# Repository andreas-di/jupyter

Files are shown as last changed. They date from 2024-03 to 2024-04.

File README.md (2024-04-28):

# Frei stehender Bogen (aus 3D-gedruckten Klötzen)

Hier findet man Dateien, welche im Zuge einer Facharbeit zur mathematischen Kettenlinie entstanden sind.
In dieser wurde ein frei stehender Bogen aus 3D gedruckten Klötzen konstruiert.

<center>

</center>

<center>
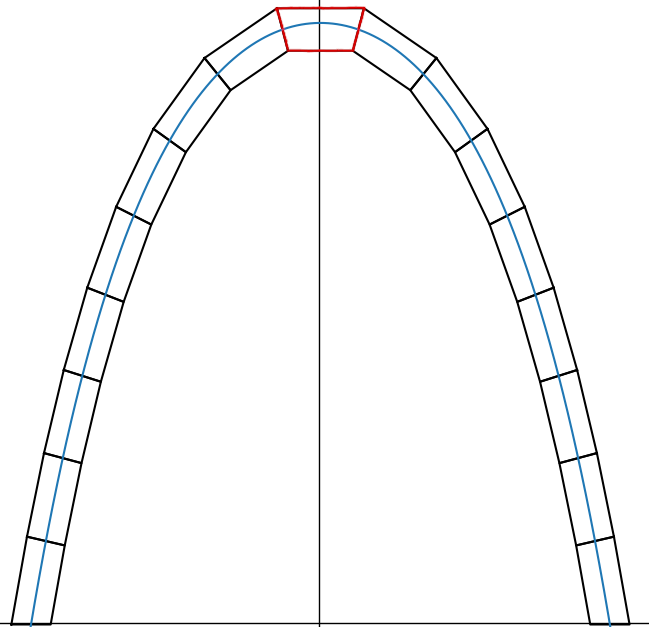
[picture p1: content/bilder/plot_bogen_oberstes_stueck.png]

</center>

Die ausführliche Facharbeit findet sich unter dem Namen Kettenlinie.pdf. Für klickbare Links bitte herunterladen und lokal öffnen.

Die Python Datei (Kettenlinie.py) erzeugt die für den Druck benötigten stl-Dateien (bei vorgegebenen Parametern) und simuliert die Klötze zweidimensional (siehe Abbildung).

Ein Jupyter-Notebook mit dem Python Code und weiterer Programm Dokumentation finden Sie [hier](https://andreas-di.github.io/jupyter/lab/index.html?path=Kettenlinie.ipynb).

Die stl-Dateien sind fertig druckbar, für einen Bogen der Länge 68cm, der Breite 30cm (am Boden). Insgesamt besteht die hier beschriebene Bogen aus 17 Klötzen, die jeweils ca. 4cm lang sind und einen Querschnitt von 2cmx2cm haben.

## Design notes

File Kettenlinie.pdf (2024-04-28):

## Die Kettenlinie Theoretische Eigenschaften und Anwendung beim Bau eines frei stehenden Bogens

Facharbeit von Andreas Diewald

### 8. M¨arz 2024

1

2

### Inhaltsverzeichnis

1 Einleitung | 3
2 Grundlagen: Herleitung der Bogenl¨ange | 5
3 Drehmatrix | 7
4 Grundlagen: Hyperbelfunktionen | 8
5 Grundlagen Kettenlinie | 12
6 Freistehender Bogen | 16

### 6.5.2 Zus¨atzliches L¨angenstuck | 29 ¨

7 Anwendung in der Architektur | 35
8 Fazit | 39
9 Literaturverzeichnis und Eigenst¨andigkeitserkl¨arung | 40

### 10 Anhang

### 10.1 Grundlagen: Matrix Vektor Rechnung | 10.1.1 Graphische Darstellung Vektoren | 10.1.2 Betrag eines Vektors | 10.1.3 Addition von Vektoren | 10.1.4 Matrix-Vektor-Multiplikation | 10.2 Numerische Werte |

3

### 1 Einleitung

Ein Jupyter-Notebook, mit dem Python-Code zu dieser Arbeit, finden Sie hier:

https://andreas-di.github.io/jupyter/lab/index.html?path=Kettenlinie.ipynb

Die vorliegende Facharbeit und weitere Dateien, wie zum Beispiel die fertig druckbaren stl-Dateien, finden Sie hier:

https://github.com/andreas-di/jupyter.

Diese Facharbeit besch¨aftigt sich mit der mathematischen Kettenlinie. Die Kettenlinie (auch Katenoide genannt) ist die mathematische Kurve, die eine Kette beschreibt, die an zwei Punkten aufgehangen ist und nach Einwirkung der Schwerkraft in der Ruhelage h¨angt.

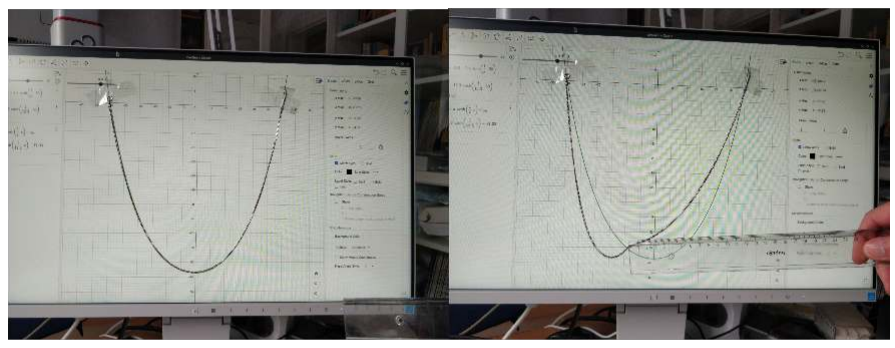
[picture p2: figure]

Abbildung 1: Eine Halskette ist mit Tesafilm am Bildschirm befestigt und man erkennt, dass ihre Form genau mit der mathematischen Katenoide ubereinstimmt. ¨

4

Ich werde auf die mathematische Beschreibung der Kettenlinie eingehen und diese anschließend an einem spezifischen Beispiel durch einen Bogen simulieren.
Dieser besteht aus einzelnen Kl¨otzen ohne statische Verbindung, welche zu einem Bogen zusammengesetzt sind. Dieses Modell illustriert besonders deutlich die zentrale Eigenschaft der Kettenlinie, wonach in keinem Punkt seitliche Schubkr¨afte wirken.
Abschließend werde ich auf die historische Bedeutung und Anwendung im Bereich der Architektur eingehen.

Erst einmal folgt jedoch eine knappe Schilderung der Geschichte der Kettenlinie.

Geschichte

Galilei (1564 bis 1642) besch¨aftigte sich erstmals mit der Kettenlinie. Er vermutete, dass die Kettenlinie, zwar nicht gleich, aber ¨ahnlich einer Parabel sei. Diese These widerlegte jedoch Joachim Jungius (1587 bis 1657) in seiner 1639 erschienenen ”

Geometria empyrica“.
Christian Huygens (1629 bis 1695) zeigt 1646 ebenfalls, dass es sich bei der Kettenlinie nicht um einem Parabel handeln k¨onne. Da Huygens jedoch nicht in der Lage war, die Kettenlinie mathematisch zu beschreiben, bat er Leibniz darum.
Die exakte Herleitung der Kettenlinie erfolgte dann erstmals 1690 durch Gottfried Wilhelm Leibniz. Da Leibniz sich bei seiner L¨osung unsicher war, rief er zum Wettbewerb auf, die Kettenlinie herzuleiten. Im Zuge dieses Wettbewerbs leiteten auch Huygens und Johann Bernoulli die mathematisch korrekte Beschreibung der Kettenlinie her.
Diese L¨osungen wurden schließlich im Juni 1691 ver¨offentlicht.

Die Darstellung der geschichtlichen Erarbeitung der Kettenlinie ist einer Ausarbeitung von [Hajiabadi] entnommen.

Gliederung der Facharbeit

Der theoretischen Erarbeitung der Kettenlinie in Kapitel 5 und dem Bau des Bogens (Ka-
pitel 6) sind die fur den Bau ben ¨ | ¨otigten Grundlagen vorangestellt (Kapitel 2 bis Kapitel
4).
Anschließend folgt die Herleitung der mathematischen Beschreibung der Kettenlinie in Kapitel 5 und die Dokumentation des Bogenbaus (Kapitel 6). Abschließend wird die historische Bedeutung der Kettenlinie in Kapitel 7 dargestellt.

5

### 2 Grundlagen: Herleitung der Bogenl¨ange

Die Bogenl¨ange ist die L¨ange, die man auf der Funktion zwischen zwei Punkten A und B
zurucklegt (siehe Abbildung 2). Legt man beispielsweise eine Schnur ¨ | uber den Funktions- ¨
graphen zwischen den beiden Punkten, ist die L¨ange der Schnur die Bogenl¨ange.

Abbildung 2: Bogenl¨ange L zwischen zwei Punkten

Um im Weiteren auf die L¨ange des freistehenden Bogens eingehen zu k¨onnen, ben¨otige ich
die allgemeine Formel fur die Bogenl ¨ | ¨ange zwischen zwei Punkten A und B.

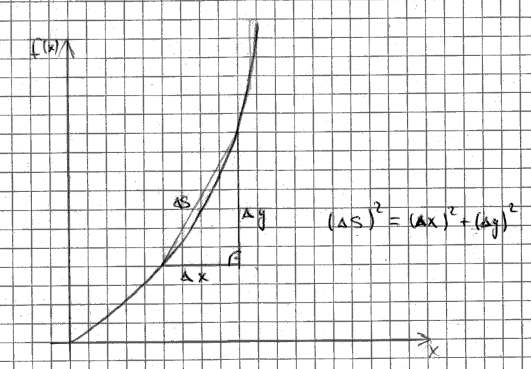
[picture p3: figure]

Abbildung 3: Ansatz Berechnung der Bogenl¨ange

6

Nach Abbildung 3 und dem Satz des Pythagoras gilt:

(∆s)

2 = (∆x)

2 + (∆y)

2
| : (∆x)

2
∆s
∆x

2
= 1 +
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
| · ∆x

(1)

Fur den Grenzfall ∆ ¨ | x → 0 gilt
∆y
∆x

2
= (f

′

(x))²
, also

ds =

q
1 + (f

′(x))²
- dx | (2)

Die Bogenl¨ange L ist die Summe aller L¨angenelemente ds auf der Strecke zwischen A und B.

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
1 + (f

′(x))²
dx | (3)
Die Formel fur die Bogenl ¨ | ¨ange findet man unter anderem in [Formelsammlung, S. 24].

7

### 3 Drehmatrix

Da in einem sp¨ateren Abschnitt in Kapitel 6.7 Punkte in einem Koordinatensystem gedreht und verschoben werden, ben¨otige ich noch Drematrizen. Daher werden diese zun¨achst noch behandelt.
Grundlagen im Bereich der Vektor-Matrix-Rechnung befinden sich im Anhang.

Der Vektor ⃗v soll gedreht um den Winkel α den Vektor ⃗v′ ergeben (siehe Abbildung 4).

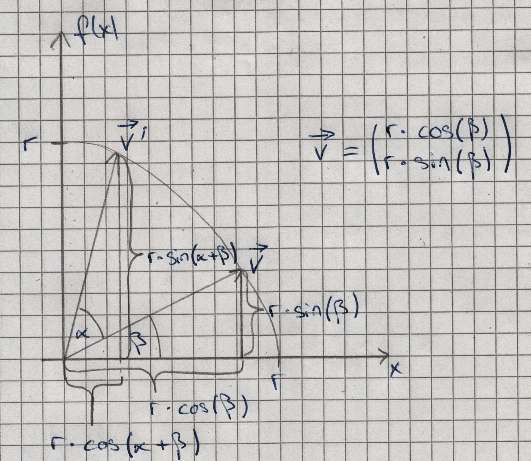
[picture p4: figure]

Abbildung 4: Der Vektor ⃗v wird mit der Drehmatrix gedreht. Der gedrehte Vektor ist hier bezeichnet mit ⃗v′

⃗v′ =

r · cos(α + β)
r · sin(α + β)
(4)
Mit den Additionstheoremen [Formelsammlung, S.14], [Muller-Fonfara, S. 318] f ¨ | ur die ¨
trigonometrischen Funktionen
sin(a + b) = sin(a) · cos(b) + cos(a) · sin(b) | (5)
cos(a + b) = cos(a) · cos(b) − sin(a) · sin(b)

ergibt sich aus Gleichung (4):

⃗v′

(5)
=
r · cos(α) · cos(β) − sin(α) · sin(β) r · sin(α) · cos(β) + cos(α) · sin(β)

| (6)

Dies kann man als Matrix-Vektor-Multiplikation (siehe Anhang Gleichung (34)) schreiben:

8

⃗v′ =

cos(α) − sin(α)
sin(α) cos(α)
·
r · cos(β)
r · sin(β)

Wobei
r · cos(β)
r · sin(β)
= ⃗v ist. Also gilt:

⃗v′ = D · ⃗v

Mit D als Drehmatrix:

D =

cos(α) − sin(α)
sin(α) cos(α)
(7)
Diese Formel fur die Drehmatrix findet man in [Fischer, S. 203] oder auch [Athen/Bru ¨ | hn,
S. 208].

### 4 Grundlagen: Hyperbelfunktionen

Da die Kettenlinie durch eine cosh-Funktion beschrieben wird, ben¨otige ich im Folgenden noch einige Grundlagen dazu. Daher werden dieses hier behandelt.

### 4.1 Cosinus hyperbolicus

Die Funktion cosh ist definiert als:

cosh(x) := e

x + e

−x
2
[Formelsammlung, S.25] | (8)

Graphische Veranschaulichung:

Abbildung 5: cosh als die ”

H¨alfte “der Summe von e

x und e

−x

9

f(x) = e

x

g(x) = e

−x

h(x) = f(x) + (g(x))
2

=

e

x + e

−x
2
= cosh(x)

Die cosh Funktion ist also die ”

H¨alfte “der Summe von e

x und e

−x

### 4.2 Sinus hyperbolicus

Die Funktion sinh ist definiert als: sinh(x) := e

x − e

−x
2
[Formelsammlung, S.25] | (9)

Graphische Veranschaulichung:

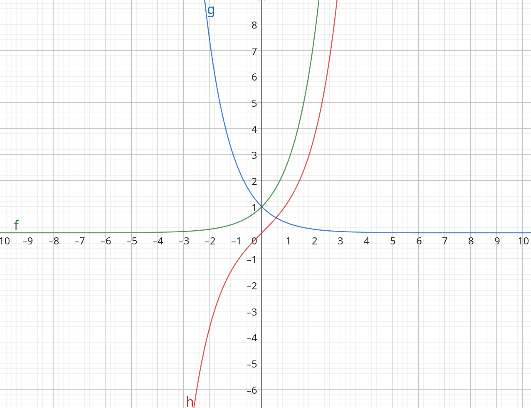
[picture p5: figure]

Abbildung 6: sinh als die ”

H¨alfte “der Subtraktion von e

x und e

−x

f(x) = e

x

g(x) = e

−x

h(x) = f(x) − (g(x))
2

=

e

x − e

−x
2
= sinh(x)

Die sinh Funktion ist also die ”

H¨alfte “der Differenz von e

x und e

−x

10

### 4.3 Ableitungen

Beim sp¨ateren Bau des freistehenden Bogen, werden die Ableitungen der cosh und sinh Funktion ben¨otigt. Daher werden diese auch noch hergeleitet.

### 4.3.1 Cosinus hyperbolicus

Mit der Kettenregel erh¨alt man:

cosh′

(x) =
e

x + e

−x
2

′

=

(e

x
)

′ + (e

−x
)

′
2

=

e

x + e

−x
- (−1)
2

=

e

x − e

−x
2

Da e

x−e⁻x
2 = sinh(x) ist, gilt:
cosh′
(x) = sinh(x) | (10)

### 4.3.2 Sinus hyperbolicus

Mit der Kettenregel eribt sich:

sinh′

(x) =
e

x − e

−x
2

′

=

(e

x
)

′ − (e

−x
)

′
2

=

e

x − e

−x
- (−1)
2

=

e

x + e

−x
2

Da e

x+e⁻x
2 = cosh(x) ist, gilt:
sinh′
(x) = cosh(x) | (11)

11

### 4.4 Zusammenh¨ange zwischen cosh und sinh

Behauptung:

cosh²

(x) − sinh²
(x) = 1 | [Formelsammlung, S.25] | (12)

Beweis:

cosh²

(x) − sinh²
(x) =
e

x + e

−x
2

2
−

| e x − e −x
| 2

2

=

e

2x + 2 · (e
x
- e

−x
) + e

−2x
4

−

e

2x − 2 · (e
x
- e

−x
) + e

−2x
4

Da (e

x
- e

−x
) = 1 ist:

=

e

2x + 2 + e

−2x
4

−

e

2x − 2 + e

−2x
4

=

e

2x + 2 + e

−2x − e

2x + 2 − e

−2x
4
=

2 + 2
4
= 1 | q.e.d

12

### 5 Grundlagen Kettenlinie

Die Kettenlinie beschreibt die Linie, in der eine Kette, aufgehangen in zwei Punkten, in der Ruhelage h¨angt (siehe Abbildung 1 aus der Einleitung).

Eine h¨angende Kette hat die Eigenschaft, dass in jedem Punkt der Kette nur tangentiale Kr¨afte wirken. Die seitliche Schubkr¨afte stehen im Gleichgewicht.
Im folgenden Unterkapitel 5.1 wird hergeleitet, dass sich eine Kettenlinie durch die Funktion
f(x) = a cosh
1
a

x

+ y0

darstellen l¨asst.

### 5.1 Herleitung Kettenlinie

Die Herleitung folgt der Darstellung von [Stifel]. Außerdem ist die Herleitung bei [Lern-Helfer]
zu finden. Einer ausfuhrlichere Ausarbeitung ist auch in [Gl ¨ | uck, S. 2] dargestellt. ¨

Betrachtet wird hier eine Kette, welche an zwei Punkten aufgehangen ist und in der Ruhelage h¨angt.
In Abbildungen 7 wird die Kettenlinie durch einzelne Massepunkte, die miteinander in Verbindung stehen, veranschaulicht. Die Kettenlinie wird hier ”

vergr¨oßert“dargestellt, indem nur einzelne Massepunkte eingezeichnet sind.

Abbildung 7: Kettenlinie simuliert durch einzelne Massepunkte

13

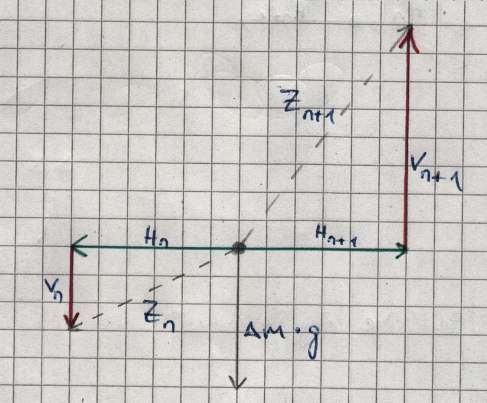
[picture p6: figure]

Abbildung 8: Einzelner Massepunkt auf der Kettenlinie

Betrachtet man einen einzelnen Massepunkt, wirken auf diesen die Kr¨afte Z, sowie die Gewichtskraft m · g.
Die Z Kr¨afte lassen sich jeweils in vertikale Kraftkomponenten V und horizontale Kraftkomponenten H unterteilen (siehe Abbildung 8).
Daher gilt bei einer Kette im Gleichgewicht:
Hn | = Hn+1 = konstant = H | (13)
Vn+1 | = Vn + ∆m · g | (14)

Gleichung (13) bedeutet, dass keine resultierenden seitlichen Schubkr¨afte wirken. Denn
wenn welche wirken wurden, w ¨ | urde sich die Form der Kette solange nach diesen ¨ | ¨andern,
bis keine mehr wirken wurden. ¨
Nur wenn Gleichung (13) gilt, h¨angt die Kette in Ruhelage.
Fur die Steigung der linken Seite des betrachteten Massepunkts gi ¨ | lt:
∆yn
∆xn

=

Vn
Hn

(15)

Und auf rechter Seite:
∆yn+1

∆xn+1

=

Vn+1

Hn+1

(16)

Da in der Ruhelage die vertikale Kraftkomponente nach unten aus der Gewichtskraft und der Teilkraft der entlang der Kette wirkenden Zugkraft entsteht (siehe Formel (14)) kann man Gleichung (16), auch schreiben als:

∆yn+1

∆xn+1

=

Vn + ∆m · g
H

=

Vn
H

+

∆m · g
H
(15)
=

∆yn
∆xn

+

∆m · g
H

14

Also ist die Steigung auf der rechten Seite gleich der Summe aus der Steigung auf der linken Seite und ∆m·g
H

∆yn+1

∆xn+1

−

∆yn
∆xn

:= ∆
∆y
∆x

Also ist die Steigung an einem beliebigen Punkt:

∆

∆y
∆x
=

∆m · g
H

(17)

Allgemein gilt:
∆m = ρ · ∆s | (18)
Wobei ρ die Masse pro L¨ange ist. Nach Einsetzten in Gleichung (17):

∆

∆y
∆x
(18)
=

ρ · ∆s · g
H

Durch Einsetzten von ∆s =

p
1 + (f

′(x))² · ∆x (siehe Grundlagen: Formel (3)), erh¨alt man:

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
ρ · g
H
- ∆x | : ∆x

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
ρ · g
H

(19)

y ist Funktion von x:

∆y
∆x

=

∆y(x)
∆x

−−→
lim ∆x→0

dy(x)
dx = y

′
(x)

Also:

∆

∆y
∆x

∆x

−−→
lim ∆x→0

∆y

′
∆x

−−→
lim ∆x→0

y

′′(x)

Also wird aus (19) die Differentialgleichung:

y

′′(x) = p
1 + (y

′(x))² ·

ρ · g
H

(20)

Ansatz zum L¨osen der Differenzialgleichung:

y(x) = a · cosh
1
a

x

+ y0 | (21)

Einsetzten von Ansatz (21) in die Differenzialgleichung (20):

a · cosh
1
a

x

− y0

′′ (21)
=

s
1 + a · cosh
1
a

x

− y0

′2
·

ρ · g
H

15

Nach Ableiten der Funktion (siehte Formel (10) und Formel (11)):

sinh
1
a

x

′
=

s
1 + sinh²
1
a

x

·

ρ · g
H

1
a
- cosh
1
a

x

=

s
1 + sinh²
1
a

x

·

ρ · g
H

Durch Beziehung cosh² − sinh² = 1 (siehe Grundlagen Hyperbelfunktionen, Gleichung (12) und Wurzel ziehen:

1
a
- cosh
1
a

x

= cosh
1
a

x

·

ρ · g
H

Wenn 1
a =

ρ·g
H wird die Differentialgleichung also erfullt durch: ¨

y(x) = a · cosh
1
a

x

+ y0

Im Folgenden werde ich die Bezeichung f(x) fur ¨ y(x) benutzen.

f(x) = a · cosh
1
a

x

+ y0 | (22)

16

### 6 Freistehender Bogen

H¨angt man an eine h¨angende Kette eine bestimmte Masse, bildet sich so die Kette so aus, dass keine seitlichen Schubkr¨afte wirken. Dreht man dieses Modell um, erh¨alt man den optimalen Bogen, um eine solche Masse zu tragen. Das liegt daran, dass genau wie bei der Kette in keinem Punkt seitliche Schubkr¨afte wirken. Diese Eigenschaft, erm¨oglichte das verwenden von H¨angemodellen in der Architektur (siehe Kapitel 7).

Dies gilt auch dann, wenn keine Masse auf dem Bogen lasten soll. Dann ist der optimale stabile Bogen die umgedrehte Kettenlinie.

Um zu veranschaulichen, dass bei einem solchen Bogen keine seitlichen Schubkr¨afte wirken, baue ich im Folgenden einen Bogen aus einzelnen Kl¨otzen, die nicht statisch miteinander
verbunden sind (siehe Abbildung 9). Wurden seitliche Schubkr ¨ | ¨afte wirken, wurden sich ¨
die Kl¨otze zur Seite weg schieben und der Bogen wurde zusammenbrechen. ¨

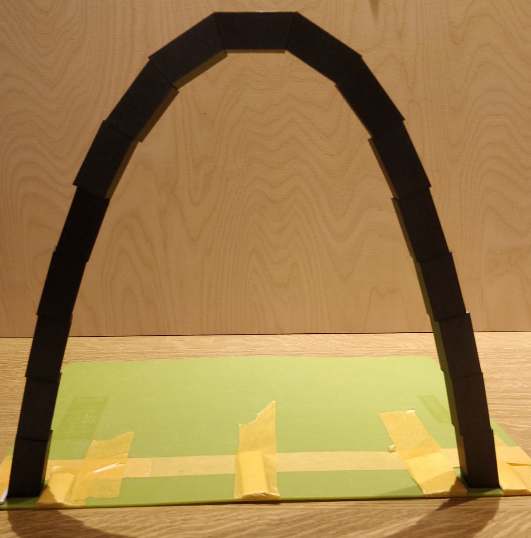
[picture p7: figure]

Abbildung 9: Freistehender Bogen aus einzelnen 3D-gedruckten Kl¨otzen. Die Kl¨otze stehen lose aufeinander und sind nicht miteinander verbunden.

17

Der Bogen wird auf dem Boden von zwei festgeklebten Erh¨ohungen festgehalten (siehe Abbildung 9). Das ist n¨otig, da an diesen stellen die Kraft von den oberen Kl¨otzen nicht komplett abgefangen wird (siehe Abbildung 10).

Abbildung 10: Die tangentiale Kraftkomponente F⃗B,t der vom Boden aufgebracht Kraft F⃗B ist kleiner als die tangentiale F⃗K1,u
. Daher ist die resutierende Kraft zur Seite gerichtet.

Da auf dem Bogen keine Masse lasten soll, wird dieser durch eine Kettenlinie beschrieben. Vor dem Bau des Bogens wird die L¨ange L und Breite B am Boden des Bogens festgelegt (siehe Abbildung 11).

18

Abbildung 11: L ist die Bogenl¨ange

Auch die Breite b und H¨ohe h der Kl¨otze (siehe Abbildung 12) werden festgelegt.

Abbildung 12: b ist die Breite des Klotzes, h seine H¨ohe

Hier wurden die Werte gew¨ahlt als:

L = 136LE
B = 60LE
b = 4LE
h = 4LE

19

Die bogenbeschreibende Funktionsgleichung soll so gew¨ahlt werden, dass der Teil unterhalb der x-Achse den Bogen beschreibt, (siehe Abbildung 13).
Daher gilt, dass die Nullstelle der Funktion x0 =

B
2 = 30LE und die Bogenl¨ange zwischen den Nullstellen −x0 und x0 gleich L ist.

Abbildung 13: Bogenbeschreibende Kettenlinie

Ich habe mich dafur entschieden, den Bogen aus 17 Kl ¨ | ¨otzen zu bauen.
Durch die ungerade Anzahl, ist der Bogen stabiler, da der obere Klotz waagerecht liegt (siehe Abbildung 14).

Abbildung 14: Oberster Klotz liegt waagerecht

### 6.1 Bogenl¨ange Kettenlinie

Um die Maße der einzelnen Kl¨otze bestimmen zu k¨onnen, muss im ersten Schritt die Funktionsgleichung der Kettenlinie bestimmt werden, die den Bogen simuliert.

20

Die bogenbeschreibende Funktion ist so ins Koordinatensystem gelegt, dass sie Achsensymmetrie aufweist und der Teil unterhalb der x-Achse den Bogen beschreibt (siehe Abbildung 15).

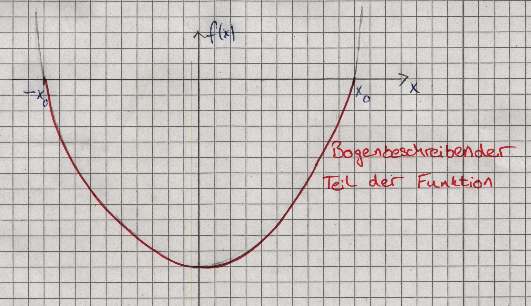
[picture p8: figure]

Abbildung 15: Teil der Kettenlinie, der den Bogen simuliert

Um den Faktor a der Kettenlinie f(x) = a · cosh

1
a

x

− y0 zu bestimmen, wird zuerst die
Gleichung fur die Bogenl ¨ | ¨ange L unterhalb der x-Achse aufgestellt.

Aus Abbildung 15 folgt, dass die Bogenl¨ange zwischen den beiden Nullstellen −x0 und
x0 gleich der L¨ange L des Bogens sein muss. Mit Formel (3) fur die allgemeine Bogenl ¨ | ¨ange
gilt:

L =

Z x0

−x0

q
1 + (f

′(x))²
dx

Da die Kettenlinie durch eine cosh Funktion beschrieben wird ( f(x) = a · cosh

1
a

x

siehe
Formel (22)), und diese abgeleitet f

′

(x) = sinh

1
a

x

ergibt (siehe Formel (10)), wird aus dieser Gleichung:

L

(10)
=

Z x0

−x0

s
1 + sinh²
1
a

x

dx | (23)

Durch die Beziehung cosh²

(x) − sinh²
(x) = 1 (siehe Grundlagen Gleichung (12)), kann man Gleichung(23) auch schreiben als:

L

(12)
=

Z x0

−x0

s
cosh²
1
a

x

dx

=

Z x0

−x0

cosh
1
a

x

dx

(11)
=

a · sinh
1
a

x

x0

−x0
= a · sinh
1
a

x0

−

a · sinh
−

1
a

x0

| (24)

21

Da die sinh Funktion punktsymmetrisch ist, gilt a ·sinh
−

1
a

x0

= −

a · sinh

1
a

x0

. Und
da (−1) · (−1) = +1 ist, kann man Gleichung (24) auch schreiben als:

L = 2a · sinh
1
a

x0

(25)

Alle Werte bis auf a sind konstant. ( x0 = 30LE und L = 136LE )
Mit Hilfe dieser Gleichung wird im nachfolgenden Kapitel der Fakor a der Funktion bestimmt.

### 6.2 Bestimmung Faktor a

Zur Beschreibung einer konkreten Kettenlinie muss der Faktors a der Funktionsgleichung (Gleichung (22)) fur die Kettenlinie bestimmt werden. ¨
L = 136LE = konstant
x0 = 30LE = konstant

L

| (25) = | 2a · sinh
| | 1 a x0

| − 2a · sinh
1
a

x0

0 | = | L − 2a · sinh
1
a

x0

(26)

Betrachtet man nun g(a) := L − 2a · sinh

1
a

x0

als Funktion von a, sind die Nullstellen dieser Funktion gesucht.
Der Wert a wird, mit einem Python-Programm (siehe Anhang) mittels Intervallhalbierung, numerisch bestimmt, da es nicht m¨oglich ist, Gleichung (26) algebraisch nach a umzustellen.

Mit den von mir verwendeten Parametern (L = 136LE, x0 = 30LE) ergibt sich mit Hilfe des Python-Programmes die Nullstelle:

| | a ≈ 12, 54

Der Wert a ist auf zwei Nachkommastellen gerundet. (Genauere Angaben befinden sich im Anhang.)

Damit sind nun alle Konstanten in der Kettenlinie (22) bestimmt. Der Faktor y0 wurde ermittelt, indem die Funktion der Kettenlinie an der Nullstelle x0 gleich Null gesetzt wurde. Dieser Ausdruck wurde nach y0 umgestellt (y0 = −a · cosh

1
a

x0

). Da a und x0 bekannt
sind, kann y0 bestimmt werden.
| | y0 ≈ −69.15

Auch dieser Wert wurde mittels des Pythonprogramms bestimmt und ist auf zwei Nachkommastellen gerundet.

22

### 6.3 Bestimmung x Wert bei gegebener Bogenl¨ange auf der Funktion

Hier wird die Kettenlinie erstmalig in gleich lange Stucke unterteilt. Dieses St ¨ | ucke werden ¨
sp¨ater durch Kl¨otze simuliert.
Die gesamte Bogenl¨ange wird durch Formel (23): L =

R x0

−x0

q
1 + sinh²

1
a

x

| dx bestimmt.

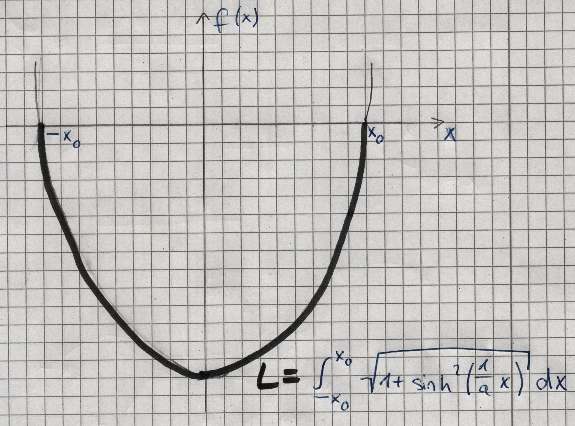
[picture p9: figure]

Abbildung 16: Bogenl¨ange zwischen den Nullstellen

Also wird die Bogenl¨ange von 0 bis zu einer Stelle x durch das Integral von 0 bis x bestimmt.

Abbildung 17: Bogenl¨ange zwischen der Stelle 0 und x

23

l

!=

Z x

0

q
1 + (f

′(x))²
dx =

Z x

0

s
1 + sinh²
1
a

x

dx

Mit der Beziehung cosh² − sinh² = 1 (siehe Formel (12)):

l

(12)
=

Z x

0

cosh
1
a

x

dx (11)
=

a · sinh
1
a

x

x

0
| = | a · sinh
| | 1 a x

− a · sinh
1
a
- 0

a · sinh
1
a
- 0

= 0
(27)
| (27)
| = | a · sinh
| | 1 a x
| : a
l a | = | sinh
| | 1 a x
| arcsinh(·)

arcsinh
l
a
| = | 1 a
- x | | · a
x | = | a · arcsinh
l
a
(28)

Mit dieser Formel l¨asst sich ein x-Wert x in Abh¨angigkeit von eine Bogenl¨ange l bestimmen. Also ist x eine Funktion von l, x = x(l) = a · arcsinh

l
a
Die Konstante a ist hier a ≈ 12, 5 (wie in Kapitel 6.2 bestimmt).

Die Bogenl¨ange L der Funktion wird in gleichlange Teile unterteilt (siehe Abbildung 18), wobei jeder dieser Teile durch einen Klotz des Bogens simuliert werden soll.

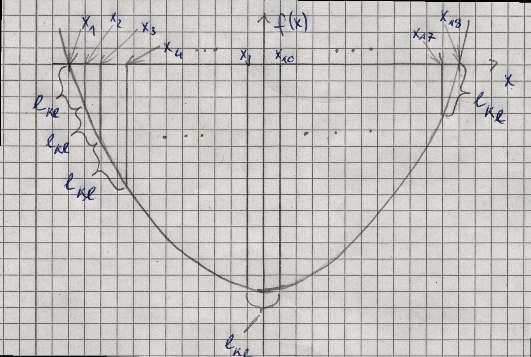
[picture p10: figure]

Abbildung 18: Bogenl¨ange unterteilt in Teill¨ange lKl

24

Die durch einen Klotz beschriebene Bogenl¨ange lKl, ist also die gesamte L¨ange L des Bogens geteilt durch die Anzahl der Kl¨otze.
Fur die Anzahl der Kl ¨ | ¨otze habe ich eine ungerade Anzahl anzahlk = 17 gew¨ahlt, sodass
der oberste Klotz des Bogens waagerecht liegt (siehe Abbildung 14).
Da ich L = 136LE gew¨ahlt habe, ist die durch einen Klotz beschriebene Bogenl¨ange hier

lKl =

136LE
17 = 8LE.
Um die Liste der x-Werten zu erhalten muss l1 nun bei −

L
2

starten und in jedem Schritt um lKl erh¨oht werden, bis l18 =

L
2

(siehe Abbildung 19).
Diese Werte fur ¨ ln werden in die Formel (28) fur einen x-Wert in Ah ¨ | ¨angigkeit der Bo-

Abbildung 19: Bogenl¨ange ln fur ¨ n = 1 und n = 2

genl¨ange l eingesetzt.
Also gilt fur den ¨ n-ten x-Wert

xn = a · arcsinh
ln
a

mit a ≈ 12, 5 und

ln = −

L
2
+ (n − 1) · lk | (29)

wobei
n = 1, 2, 3..., 18

Also ist fur ¨ n = 1 die zugeh¨orige Bogenl¨ange l1 = −

L
2

und x1 = −x0. Das gleiche gilt fur ¨ n = 18 auf positiver Seite. Also l18 =

L
2

und somit x18 = x0.

i | 1 | 2 | 3 | 4 | 5 | 6 | 7 | 8 | 9 | 10 | 11 | 12 | 13 | 14 | 15 | 16 | 17 | 18
ln | -68.0 | -60.0 | -52.0 | -44.0 | -36.0 | -28.0 | -20.0 | -12.0 | -4.0 | 4.0 | 12.0 | 20.0 | 28.0 | 36.0 | 44.0 | 52.0 | 60.0 | 68.0
xi | -30.0 | -28.5 | -26.7 | -24.7 | -22.3 | -19.4 | -15.6 | -10.7 | -3.9 | 3.9 | 10.7 | 15.6 | 19.4 | 22.3 | 24.7 | 26.7 | 28.5 | 30.0
f(xi) | 0.0 | -7.9 | -15.7 | -23.4 | -31.0 | -38.5 | -45.5 | -51.8 | -56.0 | -56.0 | -51.8 | -45.5 | -38.5 | -31.0 | -23.4 | -15.7 | -7.9 | 0.0
Die Werte in der Tabelle habe ich mittels einer for-Schleife in einem Pythonprogramm ermittelt (siehe Anhang).
Die x- und f(x)−Werte werden ben¨otigt, um die L¨angen der Kl¨otze und die Schneidewinkel an den Seiten der Kl¨otze zu bestimmen.

25

### 6.4 Bestimmung der Schneidewinkel

Um die Kl¨otze zu bauen werden die Schneidewinkel ben¨otigt, unter denen sich die Kl¨otze beruhren. Dieses werden in diesem Kapitel berechnet. ¨
Die Kl¨otze liegen so auf der Funktion, dass der Funktionsgraph genau durch die Mitte der R¨ander des Klotzes geht (siehe Abbildung 20). An diesen Stellen befinden sich die Punkte der x-Werte (siehe Abbildung 20).

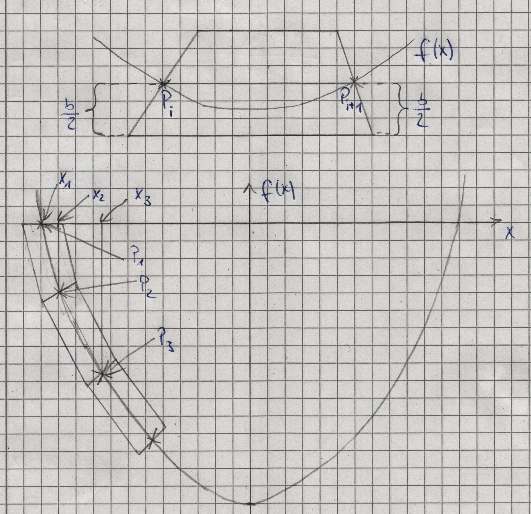
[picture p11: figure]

Abbildung 20: Lage des Funktionsgraphen in einem Klotz

Um den optimalen Bogen zu erhalten, mussten die Schneidewinkel in einem 90 ¨

◦
-Winkel
auf den wirkenden Kr¨aften stehen. Da hier die Kr¨afte tangential wirken (siehe Grundlagen Kettenlinie), w¨aren die korrekten Schneidewinkel die Normalen-Steigungswinkel.

H¨atten die Kl¨otze keine Breite, w¨are es m¨oglich diese als Schneidewinkel zu verwenden.
Doch da die Kl¨otze eine Breite haben, wurden die Kl ¨ | ¨otze nicht genau aufeinander auflie-
gen, wurde man die Normalen-Steigungswinkel verwenden, (siehe Abbildun ¨ | g 21).

26

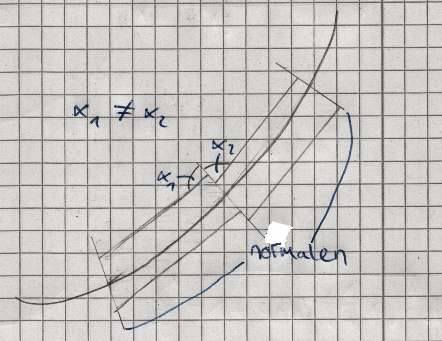
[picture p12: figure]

Abbildung 21: Lage der Kl¨otze mit Normalen als Schnitte. Die Kl¨otze wurden nicht genau ¨ aufeinander aufliegen.

Da die Außenseiten der Kl¨otze parallel zu der Sekanten durch die beiden x-Werte sind (siehe Abbildung 20), liegen die Kl¨otze genau aufeinander auf, wenn der Winkel zwischen diesen gleich dem zwischen den jeweiligen Sekanten ist.

Der Schneidewinkel λ ist dementsprechend die H¨alfte des Winkels γ zwischen den jeweiligen Sekanten, (siehe Abbildung 22).

Abbildung 22: Winkel λ =

180◦−α2+α1
2

zwischen den Kl¨otzen (siehe Formel (30))

Also gilt fur den Schneidewinkel ¨ | λ zwischen zwei Kl¨otzen:
| λ = 180◦ − α2 + α1
| 2

(30)

27

Wobei α1 und α2 die Sekanten-Steigungswinkel der jeweiligen Sekanten aus Abbildung 22 sind.

Besonderheit bei dem ersten und letzten Klotz

Da die Schneidewinkel λ jeweils von zwei Sekantensteigungen α abh¨angig sind, wurde man ¨
fur den ersten und letzten Klotz keinen Schneidewinkel an der x- ¨ | Achse erhalten, da dort
ein weiterer Sekanten-Steigungswinkel fehlt.
Da mein Python-Programm aus den Sekantensteigungswinkeln automatisch die Schneidewinkel und daraus die Klotzmaße ermittelt, w¨are es umst¨andlich, in jedem Schritt den ersten und letzten Klotz gesondert zu behandeln.
Um dies zu umgehen, habe ich den ersten und letzten Klotz an der x-Achse gespiegelt (siehe Abbildung 23) und die Sekantensteigungswinkel, die sich fur diese gespiegelten Se- ¨ kanten ergeben an die erste und letzte Stelle der Liste gestellt. Fur den ersten und letzten ¨ Schneidewinkel λ1 und λ18 gilt also λ1 = α1 und λ18 = α17 (siehe Abbildung 23)

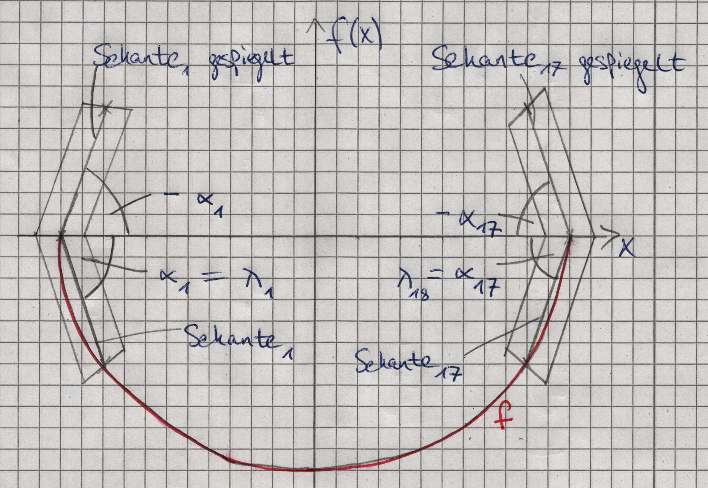
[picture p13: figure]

Abbildung 23: Erster und letzter Klotz an der x-Achse gespiegelt

Mit diesem Trick, k¨onnen alle anderen Funktionen meines Python-Programmes wie ge-
wohnt uber die als Parameter ben ¨ | ¨otigten Listen iterieren, ohne Ausnahmen beim ersten
und letzten Klotz machen zu mussen. Andernfalls m ¨ | usste in der Liste der Schneidewinkel ¨
an ersten und letzter Stelle der jeweilige Sekanten-Steigungswinkel angegeben werden.

28

Numerische Ergebnisse

In der nachfolgenden Tabelle sind die verwendeten Schneidewinkel λ dargestellt. Die Werte in der Tabelle wurden genau wie die x-Werte mit dem Pythonprogramm berechnet (siehe Anhang).

i | 1 | 2 | 3 | 4 | 5 | 6 | 7 | 8 | 9 | 10 | 11 | 12 | 13 | 14 | 15 | 16 | 17 | 18
λ | 78.9 | 89.23 | 88.98 | 88.61 | 87.98 | 86.86 | 84.66 | 80.19 | 74.04 | 74.04 | 80.19 | 84.66 | 86.86 | 87.98 | 88.61 | 88.98 | 89.23 | 78.9

### 6.5 Bestimmung der Klotz-Ausmaße

Zum Drucken der Kl¨otze werden die genauen Abmaße der Kl¨otze ben¨otigt. Diese werden in diesem Unterkapitel berechnet.

### 6.5.1 L¨ange der Sekante

Die Sekante, die den Klotz darstellt, verl¨auft an dessen Seiten genau durch die Mitten (siehe Abbildung 20). Also genau durch die Punkte, die den Klotz in seiner Lage festlegen. Jede Sekante ist, wie der zugeh¨orige Klotz von zwei Punkten und somit den zwei x-Werten abh¨angig (siehe Abbildung 24). Der Index der Sekanten gibt an, durch welche Punkte diese verl¨auft (beispielsweise verl¨auft die Sekante s1,2 durch den Punkt mit dem zugeh¨origen x-Wert x1 und den Punkt mit x-Wert x2):

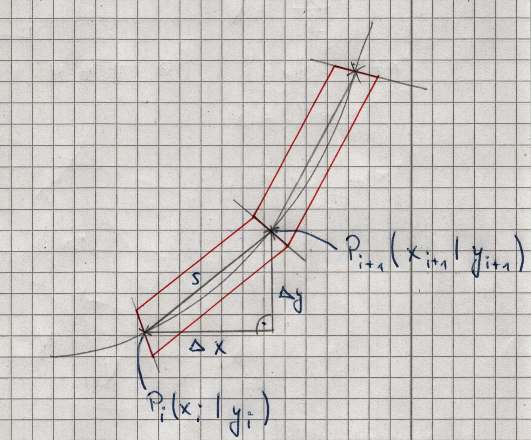
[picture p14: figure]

Abbildung 24: L¨ange der Sekante

j = i + 1
∆x = xj − xi | (31)
∆y = yj − yi

Da die Koordinaten aller Punkte auf der Funktion bekannt sind (siehe Tabelle aus Kapitel 6.3), kann die Sekanten-L¨ange s nach dem Satz von Pythagoras bestimmt werden.

29

si,j =

p
∆x

2 + ∆y

2

si,j | (31)
=

p
(xi+1 − xi)

2 + (yi+1 − yi)

2 (32)

### 6.5.2 Zus¨atzliches L¨angenstuck ¨

Da die Schneidewinkel λ bereits bestimmt wurden (siehe Tabelle in Kapitel 6.4) und die Breite b der Kl¨otze festgelegt ist (hier b = 4LE), kann die zus¨atzliche L¨ange lE,i (i ist der Z¨ahlindex, der die aktuelle x-Stelle angibt, bei der die Extral¨ange lE,i auftritt)(in Abbildung 25 ist l = lE,i) mit Hilfe des tan bestimmt werden.

Abbildung 25: L¨ange an den Seiten der Kl¨otze

tan(λ) =

b
2
lE,i

lE,i =

b
2 · tan(λ)

(33)

Zu beachten ist, dass jeder Klotz auf beiden Seiten um unterschiedliche L¨angen lE,i l¨anger ist, da die Winkel an den x-Werten ebenfalls unterschiedlich von einander sind.

### 6.5.3 L¨ange Außen

Da nun die Sekantenl¨angen mit Hilfe von Formel (32) und die zus¨atzlichen L¨angen lE,i mit Hilfe von Formel (33) bestimmt wurden, k¨onnen die finalen Klotzl¨angen bestimmt werden,
indem außen die Sekantenl¨ange mit den zwei jeweiligen zus¨atzlichen L¨angenelementen addiert werden.
Klotzk | 0 | 1 | 2 | 3 | 4 | 5 | 6 | 7 | 8 | 9 | 10 | 11 | 12 | 13 | 14 | 15 | 16
LaengeaußenkinLE | 8.4 | 8.1 | 8.1 | 8.1 | 8.2 | 8.3 | 8.5 | 8.8 | 9.0 | 8.8 | 8.5 | 8.3 | 8.2 | 8.1 | 8.1 | 8.1 | 8.4

30

### 6.5.4 L¨ange Innen

Die innere L¨ange wird ¨ahnlich wie die ¨außere bestimmt. Nur werden hier die zus¨atzlichen L¨angenelemente von der Sekantenl¨ange subtrahiert (siehe Abbildung 25).

Klotzk | 0 | 1 | 2 | 3 | 4 | 5 | 6 | 7 | 8 | 9 | 10 | 11 | 12 | 13 | 14 | 15 | 16
LaengeinnenkinLE | 7.6 | 7.9 | 7.9 | 7.9 | 7.8 | 7.7 | 7.4 | 7.0 | 6.7 | 7.0 | 7.4 | 7.7 | 7.8 | 7.9 | 7.9 | 7.9 | 7.6

Dadurch sind jetzt alle Abmaße der Kl¨otze bestimmt und der Druck der Kl¨otze kann erfolgen. Dieser ist im n¨achsten Unterkapitel beschrieben.

### 6.6 Druck der Kl¨otze

Ursprunglich wollte ich die Kl ¨ | ¨otze aus Holz bauen. Hierbei h¨atte ich die Außenl¨angen der
Kl¨otze und die Schneidewinkel ben¨otigt. Doch da ich einen 3D-Drucker besitze und der Druck h¨ochstwarscheinlich schneller, weniger fehleranf¨allig und deutlich genauer ist, habe ich mich dazu entschlossen, die Kl¨otze mit diesem zu drucken.
Fur den Druck ben ¨ | ¨otigte ich nur die Eck-Koordinaten der Kl¨otze. Diese kann ich mit
Hilfe der Sekantenl¨ange und der zus¨atzlichen L¨angenstucke bestimmen (siehe Abbildung ¨ 26).

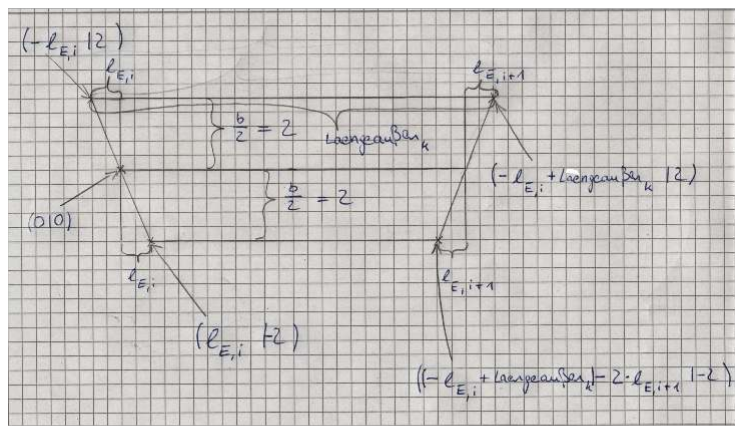
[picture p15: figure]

Abbildung 26: Eck-Koordinaten mit Punkt Pi als Nullpunkt

31

Der Punkt Pi wird als Nullpunkt gew¨ahlt. Dadurch wird es leichter, den Klotz zur Kontrolle an die richtige Position zu verschieben (siehe Kapitel 6.7).

Mit den Punkten der Ecken ist jetzt der Querschnitt eines Klotzes definiert. Im letzten Schritt habe ich daraus einen dreidimensionaler K¨orper erzeugt. Dabei wird der Querschnitt ”

nach oben gezogen“. Also erhalte ich acht Punkte, bei welchen je zwei Punkte
ubereinander liegen. F ¨ | ur die H ¨ | ¨ohe eines Klotzes habe ich hier 4LE gew¨ahlt.
Diese Punkte habe ich aus meinem Python-Programm als sogenannt stl-Datei exportiert (siehe Anhang) und gedruckt. Angaben zu den Koordinaten der Punkte befinden sich im Anhang.
Der Bogen aus Holzstucken war mit 1 ¨ | LE = 1cm geplant. Damit w¨are der Bogen ins-
gesamt 1, 36m lang und 60cm breit geworden. Kl¨otze fur solch einen Bogen zu drucken, ¨ h¨atte jedoch relativ lang gedauert. Da der Druck genauer erfolgen kann, als das Schneiden per Hand, habe ich mich dazu entschieden, die Kl¨otze auf die halbe Gr¨oße zu skalieren. Das Skalieren ist laut [Grothmann] erlaubt.

Nach dem ersten Druck war der Bogen jedoch noch realtiv instabil, da die Kl¨otze genauso breit, wie hoch waren (siehe Abbildung 27).

Abbildung 27: Relativ instabiler Bogen von der Seite. Die Kl¨otze sind nur 2cm hoch gedruckt, deshalb kippt der gesamte Bogen leicht nach rechts oder links.

32

Daher habe ich mich dafur entschieden die H ¨ | ¨ohe der Kl¨otze nach Skalieren auf 3cm zu
setzten. Dadurch sind die Kl¨otze nur 2cm breit und 3cm hoch.
Der Druck der 17 Kl¨otze mit diesen Maßen hat knapp sieben Stunden genauert.

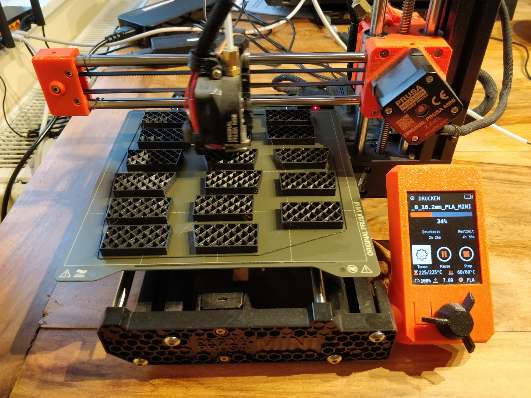
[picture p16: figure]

Abbildung 28: Laufender Druck der Kl¨otze

Da der Drucker immer an den Ecken der Kl¨otze ab und wieder ansetzt, haben sich dort Erh¨ohungen im Vergleich zur Fl¨ache gebildet (siehe Abbildung 29).

Abbildung 29: Erh¨ohung an den Ecken der Kl¨otze

Dadurch ist die Fl¨ache, mit welcher die Kl¨otze aufeinander aufliegen extrem verkleinert. Um dies zu beheben, habe ich die Kl¨otze an den Seiten abgeschliffen. So ist die Reibung gr¨oßer und der Bogen stabiler.

33

Numerische Abmaße der einzelnen Kl¨otze

Klotzk | 0 | 1 | 2 | 3 | 4 | 5 | 6 | 7 | 8 | 9 | 10 | 11 | 12 | 13 | 14 | 15 | 16
Laengeinnenk in cm | 3.8 | 4.0 | 4.0 | 3.9 | 3.9 | 3.8 | 3.7 | 3.5 | 3.4 | 3.5 | 3.7 | 3.8 | 3.9 | 3.9 | 4.0 | 4.0 | 3.8
Laengeaußenk in cm | 4.2 | 4.0 | 4.0 | 4.1 | 4.1 | 4.1 | 4.3 | 4.4 | 4.5 | 4.4 | 4.3 | 4.1 | 4.1 | 4.1 | 4.0 | 4.0 | 4.2
Der finale Bogen hat eine L¨ange von 68cm, eine Breite am Boden von 30cm, eine Klotzbreite von 2cm und eine Klotz H¨ohe von 3cm.

Abbildung 30: Verschiedene Bilder des Bogens aus verschiedenen Aufbauten

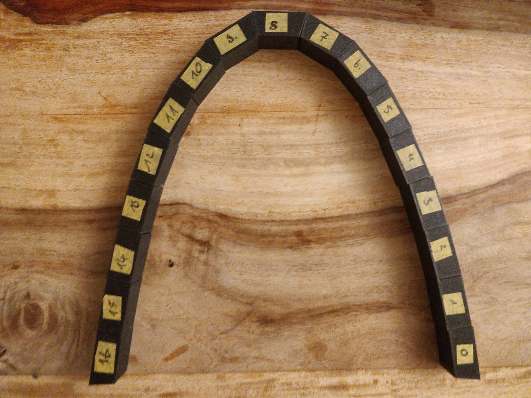
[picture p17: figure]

Abbildung 31: Liegender Bogen vor dem Hinstellen

34

### 6.7 Verschiebung der Kl¨otze mit Hilfe einer Drehmatrix

Bevor der Druck der Kl¨otze erfolgte, wollte ich mich vergewissern, dass ich keinen Fehler bei deren Berechnung gemacht habe.
Um dies zu kontrollieren, habe ich die einzelen Kl¨otze an die richige Stelle im Koordinatensystem verschoben und die Funktion mit den Kl¨otzen in meinem Python-Programm zeichnen lassen (siehe Abbildung 32).

Abbildung 32: Kl¨otze an der richtigen Stelle auf dem in blau gezeichneten Funktionsgraphen.

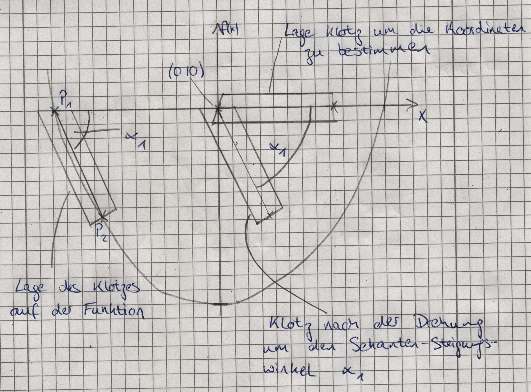
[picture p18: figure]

Abbildung 33: Drehung des Klotzes um den Sekatensteigungswinkel

Dafur habe ich die Punkte der einzelnen Kl ¨ | ¨otze (siehe Abbildung 26) als Ortsvektoren
betrachtet und um den Sekantensteigungswinkel des aktuellen Klotze gedreht (siehe Abbildung 33).

35

Da ich bei der Bestimmung der Koordinaten der Eckpunkte den Nullpunkt nicht auf eine Ecke gelegt habe, sondern auf die H¨alfte einer Seite (siehe Abbildung 26), dort wo der Funktionsgraph den Klotz schneiden wurde, ist das Verschieben ebenfalls unkompliziert. ¨ Denn der Nullpunkt der Klotzes muss dementsprechent nur auf den richtigen Punkt auf der Funktion geschoben werden. Und da die Koordinaten der Klotzpunkte bekannt sind (siehe Tabelle aus Kapitel 6.3), ist der Vektor der zum Verschieben ben¨otigt wird direkt klar.
Jeder Klotzk hat vor dem Drehen und Verschieben die Punkte Ak, Bk, Ck, und Dk. Jetzt werden diese Punkte mit der Drehmatrix D multipliziert (siehe Grundlagen Formel (7)).

D =

cos(α) − sin(α)
sin(α) cos(α)

Und anschließend werden sie mit dem Ortsvektor ⃗ai des aktuellen Punktes addiert. Daraus
ergibt sich fur die Punkt ¨ | A′
k

, B′
k

, C

′
k

, und D′
k

:

A

′
k = Ak · D + ⃗ai
B

′
k = Bk · D + ⃗ai
C

′
k = Ck · D + ⃗ai
D′
k = Dk · D + ⃗ai
Macht man diese Rechnung fur jeden Klotz und l ¨ | ¨asst die daraus entstandenen Kl¨otze
zeichnen, erh¨alt man Abbildung 32. Da der in Abbildung 32 gezeichnete Bogen korrekt
ist, habe ich folglich keine Fehler bei der Berechnung der fur den Bogen ben ¨ | ¨otigten Werte
gemacht, so dass ich die Kl¨otze ohne Fehlversuch drucken konnte.

### 7 Anwendung in der Architektur

Die Kettenlinie spielt uberwiegend im Bereich der Bogenkonstruktion und im Br ¨ | uckenbau ¨
eine Rolle.

Bogenkonsturktion

Das wohl offensichtlichste und bekannteste Beispiel fur eine Anwendung der Kettenlinie ¨ im Bogenbau ist das Gateway Arch in Missouri, Vereinigte Staaten (siehe Abbildung 34).

36

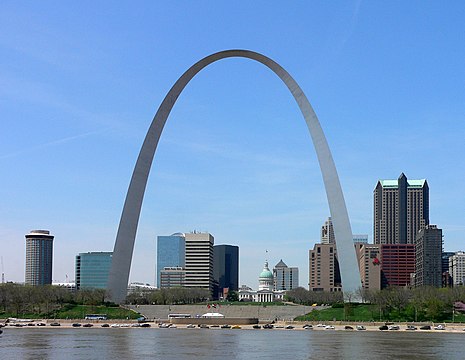
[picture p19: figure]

Abbildung 34: Gateway Arch (Missouri, Vereinigte Staaten) Bildquelle: Wikipedia, Lizenz: CC-BA-SA 3.0
https://upload.wikimedia.org/wikipedia/commons/thumb/b/b9/St_Louis_Gateway_Arch.jpg/465px-St_Louis_Gateway_Arch.jpg (https://upload.wikimedia.org/wikipedia/commons/thumb/b/b9/St_Louis_Gateway_Arch.jpg/465px-St_Louis_Gateway_Arch.jpg)

Die Konstruktion ist jedoch nur eine Ann¨aherung an die Kettenlinie. Dieses korrekt zu realisieren war schierig, da das belasten der Kettenkurve mit einer Masse die Kettenkurve beeinflusst.

Verwendung von H¨angemodellen

H¨angemodelle sind an Ketten uberkopf aufgehangene Modelle. Mit Hilfe dieser k ¨ | | ¨onnen
Tragwerke von Geb¨auden simuliert werden.

So wurde beispielsweise die Sagrada Fam´ılia von Antonio Gaud´ı (1852 bis 1926) mit Hilfe
von H¨angemodellen geplant. Dafur h ¨ | ¨angte er Massestucke mit F ¨ | ¨aden an eine Kette (siehe
Abbildung 35).

Dreht man diese H¨angemodelle um, ergeben die Ketten/Schnure die Form eines stabilen ¨
Bogens fur die darauf lastende Masse (diese Masse wurde an die Ketten/Schn ¨ | | ure dran ¨
gehangen um den Bogen zu simulieren). Die Bestimmung der Kettenkurven erfolgt jedoch bei Gaud´ı noch empirisch.
Vor der Entwicklung von Computerprogrammen zur Bogenkonstruktion war der Bau mit Hilfe von H¨angemodellen eine g¨angige Methode.
Die Schilderung der Verwendung von H¨angemodellen ist einer Publikation von [Graefe] entnommen.

37

Abbildung 35: H¨angemodelle der Sagrada Fam´ılia; Bildquelle: Wikipedia, Lizenz: CC-BA-SA 3.0
https://de.wikipedia.org/wiki/H%C3%A4ngemodell

Bruckenbau ¨

Im Bau ”

normaler“Brucken wurden die tragenden B ¨ | ¨ogen ebenfalls mittels der Kettenlinie
gebaut. Der Bau von H¨angebrucken ist jedoch interesanter zu betrachten, da die tragenden ¨ Seile die Form einer Parabel bilden. Das liegt daran, dass sich eine Kettenlinie, an welche eine Masse homogen verteilt aufgehangen ist (wie beispielsweise bei einer H¨angebrucke), zu ¨ einer Parabel ausformt (siehe [Hajiabadi, S. 10]). Also k¨onnen die Seile einer H¨angebrucke ¨ durch eine h¨angende Kette, auf welche eine Masse homogen aufgeteilt ist simuliert werden, (siehe Abbildung 36).

38

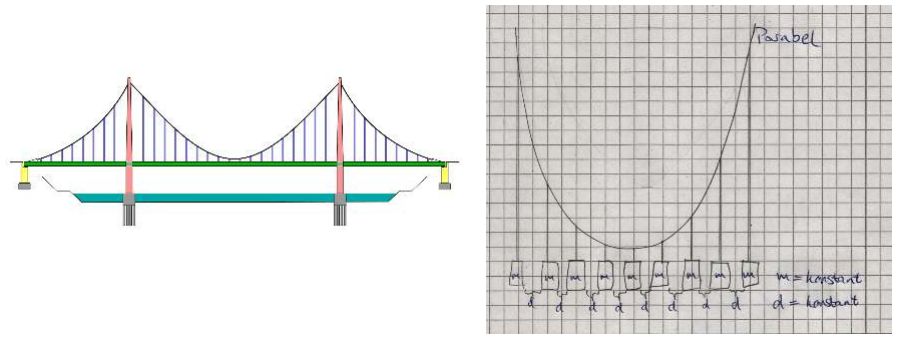
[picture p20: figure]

Abbildung 36: Grune Fahrbahn wird durch die homogene Massenverteilung simuliert. ¨ | Die
Parabel simuliert das tragende Seil
Bildquelle: Wikipedia, Lizenz: CC-BA-SA 3.0 : https://de.wikipedia.org/wiki/H%C3%A4ngebr%C3%BCcke#/media/Datei:H%C3%A4ngebr%C3%BCcke_Schema.svg (https://de.wikipedia.org/wiki/H%C3%A4ngebr%C3%BCcke#/media/Datei:H%C3%A4ngebr%C3%BCcke_Schema.svg)

Außerhalb der Architektur findet die Kettenlinie ebenfalls Anwendung in der Kunst und im Design. So sind beispielweise im McDonalds-Logo (siehe Abbildung 37) zwei Kettenlinien enthalten (siehe [Hajiabadi, S. 2]).

Abbildung 37: Zwei Kettenlinie im McDonalds-Logo. Bildquelle: Wikipedia, Lizenz: CC-BA-SA 3.0
https://upload.wikimedia.org/wikipedia/commons/thumb/3/36/McDonald%27s_Golden_Arches.svg/400px-McDonald%27s_Golden_Arches.svg.png (https://upload.wikimedia.org/wikipedia/commons/thumb/3/36/McDonald%27s_Golden_Arches.svg/400px-McDonald%27s_Golden_Arches.svg.png)

39

### 8 Fazit

Durch den Bau des frei stehenden Bogens habe ich nicht nur Einblicke in die theoretische Mathematik der Kettenlinie erhalten, sondern habe diese an einem praktischen Beispiel veranschaulicht und so mein eigenes Verst¨andis vertieft.
Um den Fehler beim Bestimmen der numerischen Ergebnisse zu vermindern, schrieb ich ein Python Programm, welches mit den Parametern der Bogenl¨ange L, der Breite B und
der Klotzbreite b (siehe Kapitel 6) alle fur den Bau ben ¨ | ¨otigten Werte bestimmt und auto-
matisch die stl-Dateien der Kl¨otze liefert. Diese werden ben¨otigt, um die Kl¨otze mit dem 3D-Drucker zu drucken.

Das Schreiben dieses Programmes war realtiv zeitaufwendig, da ich mich zuerst mit der Programmiersprache Python auseinander setzten musste, die ich bis dato nicht so gut beherrschte, dass ich ein solche Programm ohne Schwierigkeiten h¨atte schreiben k¨onnen. Doch diese Zeitinvestition erm¨oglicht es mir, jetzt einen beliebigen Bogen ohne viel h¨andische Rechnerei zu bauen oder zu simulieren, da das Programm auch die M¨oglichkeit bietet den Bogen zu zeichnen.

Im Zuge der Facharbeit habe ich mich in das professionelle Setztprogramm LATEX eingearbeitet. Dies war zwar ebenfalls relativ aufwendig, doch da dieses Programm g¨angig
fur wissenschaftlich Arbeiten ist, kann ich meine Kenntnisse gut ¨ | in einem potenziellen
Studium anwenden.

40

### 9 Literaturverzeichnis und Eigenst¨andigkeitserkl¨arung

### Literatur

[Athen/Bruhn] Athen/Bruhn: Lexikon der Schul-Mathematik, Teil 1, Weltbild Verlag, Augsburg 1994

[Fischer] | Fischer, Gerd: Lineare Algebra, Vieweg, Braunschweig 1986
[Formelsammlung] | Sieber, H.: Mathematische Formeln. Erweiterte Ausgabe E, Klett
Schulbuchverlag, Stuttgart 1994
[Gluck] | Gl ¨ | uck, Bernd: Die Kettenlinie in der Mechanik und ihr Pendant bei ¨
der W¨armeleitung in Rippen, 2022, https://berndglueck.de/dl/?dl=Waermeuebertragung+Kettenlinie-Rippentemperatur.pdf, (https://berndglueck.de/dl/?dl=Waermeuebertragung+Kettenlinie-Rippentemperatur.pdf) abgerufen am 24.02.2024
[Graefe] | Graefe, Rainer: Zum Entwerfen mit Hilfe von H¨angemodellen, Zeit-
schrift Werk, Bauen + Wohnen, Band 70, Heft 11, 1983, https: //doi.org/10.5169/seals-53542, abgerufen am 24.02.2024
[Grothmann] | Grothmann, | R.: | Die | Kettenlinie. | Geometische | Ei-
genschaften | der | Kettenkurve, | http://mathsrv.ku-
eichstaett.de/MGF/homes/grothmann/Projekte/Kettenlinie/geometrie.html, abgerufen am 24.02.2024
[Hajiabadi] | Hajiabadi, | Maikel: | Die | Kettenlinie, | Univerist¨at | Mainz,
Wintersemester | 2016/17, | https://download.uni-mainz.
de/mathematik/Algebraische%20Geometrie/Lehre/ Sem-Ausgewaehlte-hoehere-Kurven-WS2016-17/Hajiabadi%
20Maikel_Die%20Kettenlinie_090217.pdf, (https://download.uni-mainz.de/mathematik/Algebraische%20Geometrie/Lehre/Sem-Ausgewaehlte-hoehere-Kurven-WS2016-17/Hajiabadi%20Maikel_Die%20Kettenlinie_090217.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) | abgerufen | am
| 24.02.2024
[Lern-Helfer] | Lern-Helfer: Die Kettenlinie, 2010, https://www.lernhelfer.
de/schuelerlexikon/mathematik-abitur/artikel/ die-kettenlinie#, (https://www.lernhelfer.de/schuelerlexikon/mathematik-abitur/artikel/die-kettenlinie#) abgerufen am 24.02.2024
[Muller-Fonfara] | M ¨ | uller-Fonfara, Robert: Mathematik.verst ¨ | ¨andlich, Bassermann,
| Munchen 2004 ¨
[Stifel] | Stifel, Michael: https://mathepedia.de/Kettenlinie.html, abge-
rufen am 24.02.2024

Eigenst¨andigkeitserkl¨arung

Ich erkl¨are, dass ich die Facharbeit ohne fremde Hilfe angefertigt und nur die im Literaturverzeichnis angefuhrten Quellen und Hilfsmittel benutzt habe. ¨

### 10 Anhang

### 10.1 Grundlagen: Matrix Vektor Rechnung

Die fur die Drehmatrix (Kapitel 3) verwendeten Grundlagen werden hier ¨ | behandelt.

Vektoren sind mathematische Objekte, die sowohl eine Gr¨oße als auch einen Richtung haben.
(Ein Vektor ist eine Klasse von paralleler, gleichlanger, gleichgerichteter Pfeile.) Matrizen sind zweidimensionale Anordnungen von Zahlen in Form einer Tabelle.

### 10.1.1 Graphische Darstellung Vektoren

Vektoren k¨onnen als Pfeile in einem Koordiatensystem visualisiert werden. Hierbei ist die L¨ange des Pfeils die Gr¨oße des Vektors. Die Richtung des Vektors wird aus den einzelnen Komponenten ersichtlich.
Fur einen zweidimensionalen Vektor ¨ | ⃗aϵR
| 2 , schreibt man:
| ⃗a =
| a1
| a2

Wobei a1 die Entfernung parallel zur x-Achse ist und a2 die Entfernung parallel zur y-Achse.
Der Vektor ⃗a =
1
3
| ist in Abbildung 38 visualisiert.

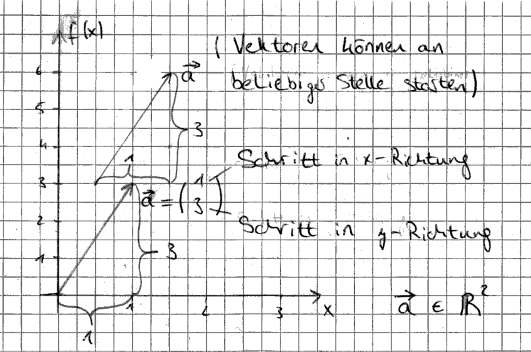
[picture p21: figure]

Abbildung 38: Vektoren k¨onnen parallel beliebig verschoben werden. Dargestellt sind zwei Pfeile, die zum selben Vektor ⃗a geh¨oren.

Fur einen dreidimensionalen Vektor ¨ | ⃗aϵR

3
, schreibt man:

⃗a =

a1
a2
a3

Wobei a1 die Entfernung parallel zur x-Achse ist, a2 die Entfernung parallel zur y-Achse und a3 die Entfernung parallel zur z-Achse ist.

Der Vektor ⃗a =

2
3
−1
- ist in Abbildung 39 visualisiert.

Abbildung 39: Zwei verschiedene Vektoren im dreidimensionalen Raum

### 10.1.2 Betrag eines Vektors

Der Betrag eines Vektors ⃗a wird mit dem gleichen Variablennamen a, ohne Vektorpfeil, bezeichnet.
a := |⃗a|

Der Betrag wird nach dem Satz von Pythagoras bestimmt (siehe Abbildung 39).

a = |⃗a| =

q
a

2
1 + a

2
2 + a

2
3

### 10.1.3 Addition von Vektoren

Die Addition von Vektoren wird in Kapitel 6.7 angewant, um Punkte in einem Koordinatensystem zu verschieben. Weshalb dies geht, und wie Vektoren addiert werden, wird hier behandelt.
Vektoren werden addiert, indem die einzelnen Komponenten addiert werden.

⃗a +⃗b :=
a1 + b1
a2 + b2

Die Addition von Vektoren ist kommutativ.

### 10.1.4 Matrix-Vektor-Multiplikation

Durch bestimmte Matrizen (Drehmatrizen) k¨onnen Vektoren im Koordinatensystem um den Koordinatenursprung gedreht werden. Diese Drehung wird durch eine Matrix-Vektor-Multiplikation beschrieben.
Der Vektor

⃗b =

b1
b2

soll mit der Matrix

A =

a11 | a12
a21 | a22

multipliziert werden. Die Multiplikation einer Matrix mit einem Vektor erfolgt durch die Multiplikation von Zeile mal Spalte.

A ·

⃗b :=
a11 · b1 + a12 · b2
a21 · b1 + a22 · b2

Oder allgemein geschrieben als:

A ·

⃗b =

Pn

i=1

a1i

- bi
Pn

i=1

a2i

- bi
(34)

Hier n = 2, da es sich um eine 2 × 2 Matrix handelt.

### 10.2 Numerische Werte

Faktoren der Funktionsgleichung

Die allgemeine Funktionsgleichung fur eine Kettenlinie (22) lautet: ¨

f(x) = a cosh
1
a

x

− y0

Die Faktoren a und y0 fur die Bogen beschreibende Funktion lauten in meinem Fall: ¨

a ≈ 12.541937507689 y0 ≈ −69.14694637731643

Diese Werte habe ich mittels meines Pythonprogrammes bestimmt.
Die Bogen beschreibende Funktion lautet also:
f(x) = 12.541937507689 cosh | 1
12.541937507689
| x
| − 69.14694637731643

# Python Programm Dokumentation

## March 7, 2024

Der Code wird im Folgenden erst beschrieben und unter der jeweiligen Beschreibung eingebunden.

# 1 Python Porgramm frei stehender Bogen

Zu Beginn werden die für das Programm benötigten Python Bibliotheken importiert.

## [1]: import math import numpy as np import matplotlib.pyplot as plt from shapely.geometry import Polygon from stl import mesh

## 1.1 Bestimmung der Funktionsgleichung

Für den Bau des Bogens, hab ich bestimmte Parameter festgelegt, die der Bogen erfüllen soll.

Einerseits die Länge L des Bogens (Bogenlänge zwischen den Nullstellen) und die Nullstelle x0 ,
bzw. die Hälfte der Bogenbreite (siehe Abbildung). Zu dem ist die Anzahl an Klötzen, die Breite eines Klotzes und die durch einen Klotz beschriebene Bogenlänge determiniert. Der Bogen wird durch eine hängende Kette beschrieben.

1

Hier werden die Parameter des Bogens initialisiert. Die Bogenlänge L hat hier den Variablennamen
L. Die Nullstelle x0 den Namen x0.

[2]: L = 136
x0 = 30

### anzahlKloetze = 17 laengeDurchKlotzSimuliert = 8 #die Bogenlänge, die durch einen Klotz simuliert␣

# ↪wird

### breiteKloetze = 4

# 2 Ermittlung Faktor a als Nullstelle von g(a) mittels Intervallhal-

# bierung durch eine rekursive Python-Funktion

# Für die Funktion, welche die Kette beschreibt, gilt: f(x) = a ⋅ cosh (

1
a

x) + y0

## (siehe PDF, Kapitel

5)

2

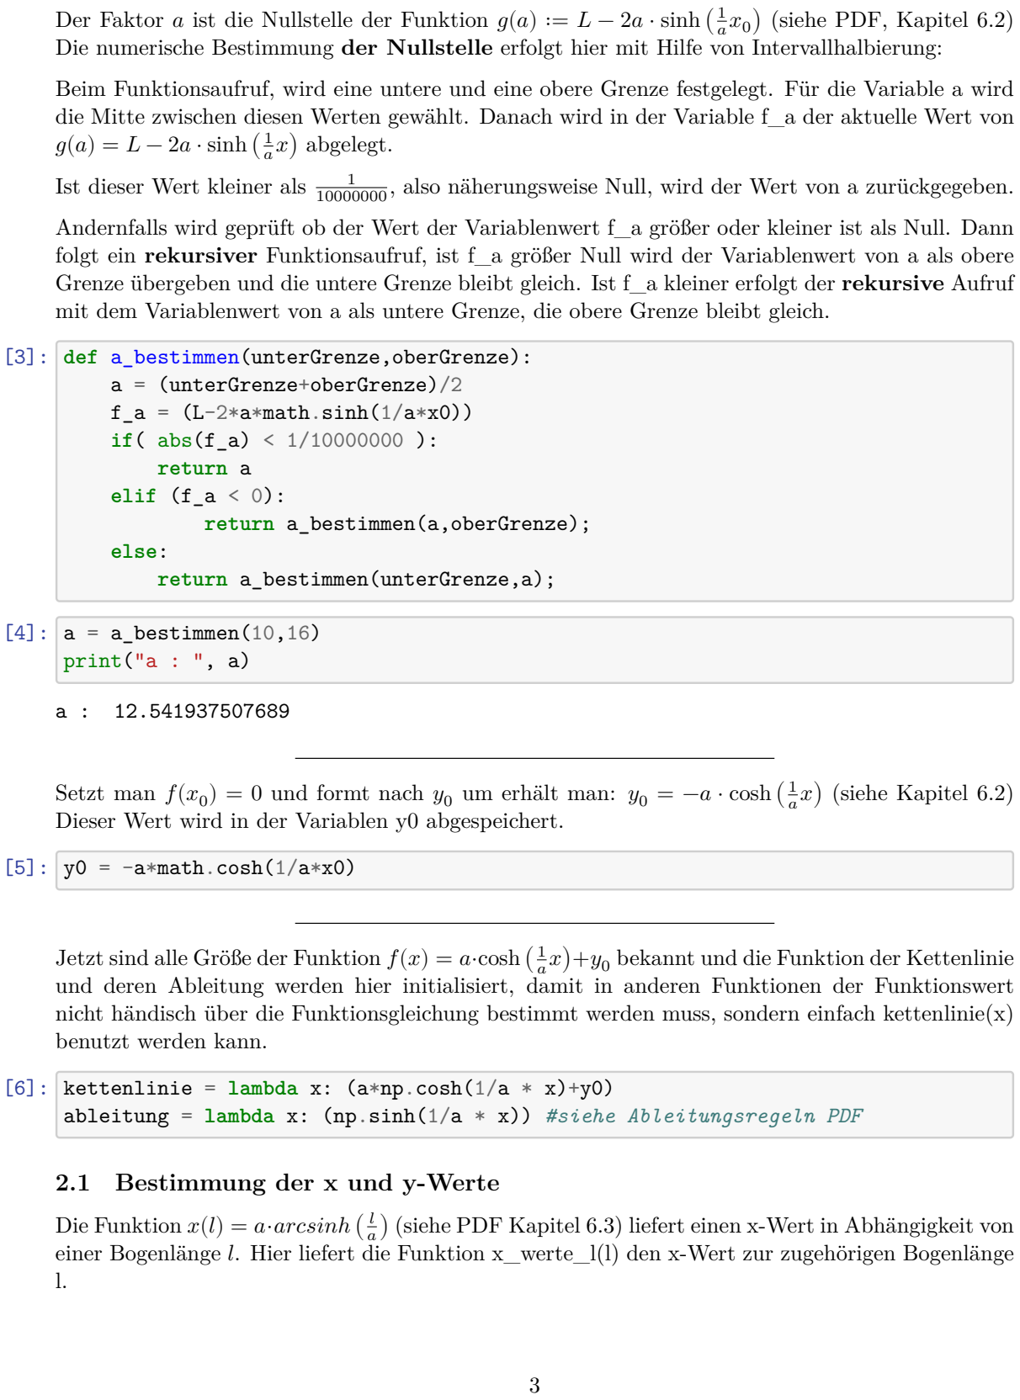
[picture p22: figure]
) (siehe PDF, Kapitel 6.2); g(a) = L − 2a ⋅ sinh (; x) abgelegt.; Ist dieser Wert kleiner als; a = (unterGrenze+oberGrenze)/2 f_a = (L-2*a*math.sinh(1/a*x0)) if( abs(f_a) < 1/10000000 ): return a elif (f_a < 0): return a_bestimmen(a,oberGrenze);; else: return a_bestimmen(unterGrenze,a);; [4]: a = a_bestimmen(10,16) print("a : ", a); a : 12.541937507689 Setzt man f(x0; x) (siehe Kapitel 6.2); [5]: y0 = -a*math.cosh(1/a*x0); benutzt werden kann.; 2.1 Bestimmung der x und y-Werte; Die Funktion x(l) = a⋅arcsinℎ ( l a

# Der Faktor a ist die Nullstelle der Funktion g(a) ∶= L − 2a ⋅ sinh (

## Die numerische Bestimmung der Nullstelle erfolgt hier mit Hilfe von Intervallhalbierung:

Beim Funktionsaufruf, wird eine untere und eine obere Grenze festgelegt. Für die Variable a wird die Mitte zwischen diesen Werten gewählt. Danach wird in der Variable f_a der aktuelle Wert von 10000000 , also näherungsweise Null, wird der Wert von a zurückgegeben.

Andernfalls wird geprüft ob der Wert der Variablenwert f_a größer oder kleiner ist als Null. Dann folgt ein rekursiver Funktionsaufruf, ist f_a größer Null wird der Variablenwert von a als obere Grenze übergeben und die untere Grenze bleibt gleich. Ist f_a kleiner erfolgt der rekursive Aufruf mit dem Variablenwert von a als untere Grenze, die obere Grenze bleibt gleich.

### [3]: def a_bestimmen(unterGrenze,oberGrenze):

# ) = 0 und formt nach y0 um erhält man: y0 = −a ⋅ cosh (

Dieser Wert wird in der Variablen y0 abgespeichert.

# Jetzt sind alle Größe der Funktion f(x) = a⋅cosh (

# x)+y0 bekannt und die Funktion der Kettenlinie

und deren Ableitung werden hier initialisiert, damit in anderen Funktionen der Funktionswert nicht händisch über die Funktionsgleichung bestimmt werden muss, sondern einfach kettenlinie(x)

### [6]: kettenlinie = lambda x: (a*np.cosh(1/a * x)+y0) ableitung = lambda x: (np.sinh(1/a * x)) #siehe Ableitungsregeln PDF

# ) (siehe PDF Kapitel 6.3) liefert einen x-Wert in Abhängigkeit von

einer Bogenlänge l. Hier liefert die Funktion x_werte_l(l) den x-Wert zur zugehörigen Bogenlänge

### [8]: x_werte_l = lambda l: (np.arcsinh(l/a) * a)

Um eine Liste der benötigten x-Werte zu erhalten, läuft in der folgenden Funktion eine for Schleife von -(der Hälfte der vorgegebenen Bogenlänge (Nullstelle im negativen Bereich)) bis zur +(Hälfte der vorgegeben Bogenlänge (Nullstelle auf positiver Seite)). In jedem Schleifendurchlauf, wird i um die größe der Variable laengeDurchHolzStueckeSimuliert (Länge vom Bogen, welche durch einen Klotz beschrieben wird) erhöht, und mit diesem i wird die Funktion x_werte_l(l) aufgerufen. i ist also praktisch die momentane Bogenlänge. Der Rückgabewert wird zur Liste hinzugefügt.

### [21]: def x_werte_holzstuecke(): x_werte_holzstuecke = [] #die Liste wird initialisiert for i in range (-int(L/2), int(L/2+1), laengeDurchKlotzSimuliert):␣ ↪#for-Schleife die über die Bogenlänge iteriert

### x_werte_holzstuecke.append(x_werte_l(i)) #die Liste wird um den␣ ↪Rückgabewert der Funktion x_werte_l(i) erweitert

### return x_werte_holzstuecke #die Liste wird zurückgegeben

### [22]: x_werte = x_werte_holzstuecke() #in der Variable x_werte wird die Liste der␣

# ↪x-Werte gespeichert

### print("x Werte:") print(x_werte)

### x Werte:

[-30.000000004186834, -28.459695195406937, -26.708667641693076, -24.682268897417455, -22.282466596571965, -19.352603653310144, -15.629065100279782, -10.666755857440647, -3.9351171525557147, 3.9351171525557147, 10.666755857440647, 15.629065100279782, 19.352603653310144, 22.282466596571965, 24.682268897417455, 26.708667641693076, 28.459695195406937, 30.000000004186834]

Um eine Liste mit den zugehörigen y-Werte zu bekommen, läuft die folgende Funktion durch die Liste der x-Werte, welche als Parameter übergeben wird, und fügt den jeweiligen Funktionswert von kettenlinie = lambda x: (anp.cosh(1/a x)+y0) zur Liste hinzu.

### [11]: def y_werte_holzstuecke(xWerteListe):

### [12]: y_werte = y_werte_holzstuecke(x_werte)

### y Werte:

[2.2700234580952383e-08, -7.8501259341093075, -15.655823782564553,

4

-23.39434867569104, -31.024771774511088, -38.466330404901925, -45.53973992575219, -51.78894544268181, -55.982593128987965, -55.982593128987965, -51.78894544268181, -45.53973992575219, -38.466330404901925, -31.024771774511088, -23.39434867569104, -15.655823782564553, -7.8501259341093075, 2.2700234580952383e-08]

## 2.2 Bestimmung der Winkel zwischen den Klötzen

## Um die Winkel zwischen den Klötzen zu bestimmen, werden die Sekanten-Steigungswinkel der Klötze benötigt. Die folgende Funktion bestimmt den Steigungswinkel der Sekante durch die Punkte p1 und p2:

### [23]: def sekantenSteigungsWinkel(p1, p2): #p1 und p2 werden als Parameter übergeben m = (kettenlinie(p1)-kettenlinie(p2))/(p1-p2) #Steigung wird bestimmt return (np.arctan(m)/(2 * math.pi) * 360) #bestimmung des Steigungswinkels␣

# ↪und umrechnen von Radiant in Grad

Die folgende Funktion liefert eine Liste mit den Sekantensteiungswinkeln, welche jeweils durch einen Klotz laufen. Dafür wird erst der erste Steiungswinkel hinzugefügt und zu letzt der letzte (siehe PDF Kapitel 6.4). Dazwischen läuft eine for-Schleife durch die Liste der x-Werte und ruf jeweils

## die Funktion sekantenSteigungsWinkel(x_werte[i], x_werte[i+1]) mit dem momentanen und dem

darauf folgenden x-Wert auf.

### [24]: def sekantenSteigungsWinkelListe(x_werte): steigungsWinkel = [] steigungsWinkel.append( np.arctan(␣ ↪(kettenlinie(x_werte[0])-(-1)*kettenlinie(x_werte[1]))/ ↪(x_werte[0]-x_werte[1]) ) / (2*math.pi)*360 ) # siehe PDF Besonderheiten␣

# ↪erster und letzter Klotz

### for i in range(0,len(x_werte)-1): # von 0 bis len-1 steigungsWinkel.append(sekantenSteigungsWinkel(x_werte[i],␣

# ↪x_werte[i+1]))

### steigungsWinkel.append( np.arctan(␣ ↪(kettenlinie(x_werte[len(x_werte)-1])-(-1)*kettenlinie(x_werte[len(x_werte)-2]))/ ↪(x_werte[len(x_werte)-1]-x_werte[len(x_werte)-2]) ) / (2*math.pi)*360 ) ##

### return steigungsWinkel

### [64]: sekantenSteigungswinkelWerteListe = sekantenSteigungsWinkelListe(x_werte) print("Sekanten-Steigungswinkel:") print(sekantenSteigungswinkelWerteListe)

### Sekanten-Steigungswinkel:

[78.898795820709, -78.898795883317, -77.35633239230725, -75.32608580825179, -72.54140437136391, -68.50963158917503, -62.2370737375766, -51.54795029298983, -31.92190536112552, -0.0, 31.92190536112552, 51.54795029298983, 62.2370737375766, 68.50963158917503, 72.54140437136391, 75.32608580825179,

5

77.35633239230725, 78.898795883317, -78.898795820709]

Mit Hilfe dieser Sekanten-Steigungswinkel wird nun der “Schneidewinkel”, bzw. die Hälfte des Winkels zwischen den Klötzen (siehe PDF Kapitel 6.4), bestimmt. Dafür läuft die nachfolgende Funktion durch die Liste der Sekanten-Steigungswinkel und bestimmt nach Gleichung (30) (siehe

PDF Kapitel 6.4) den Winkel λ (Hälfte des Winkels zwischen den Klötzen).

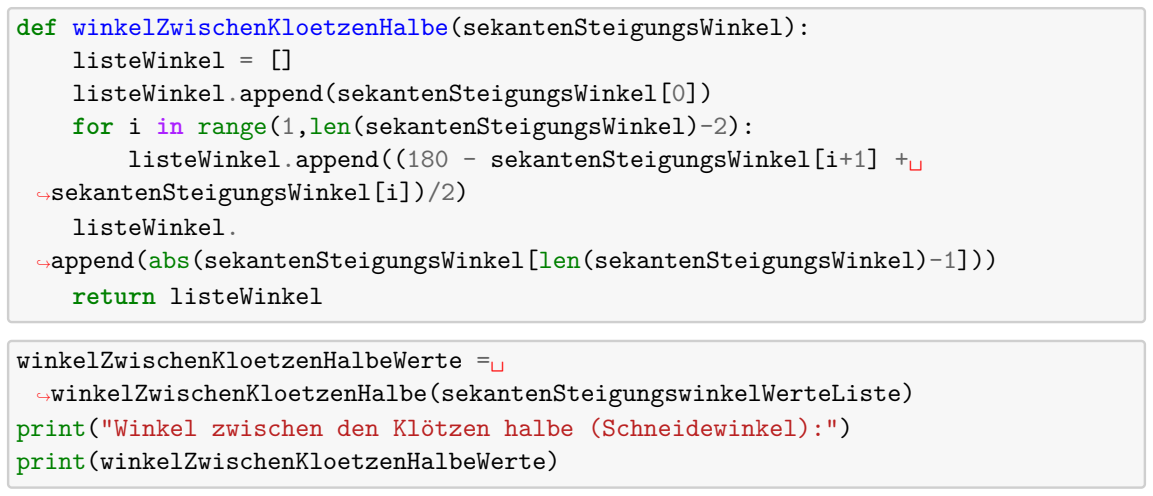
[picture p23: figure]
listeWinkel = []; listeWinkel.; return listeWinkel; print(winkelZwischenKloetzenHalbeWerte)

### [30]: def winkelZwischenKloetzenHalbe(sekantenSteigungsWinkel):

### listeWinkel.append(sekantenSteigungsWinkel[0]) for i in range(1,len(sekantenSteigungsWinkel)-2): listeWinkel.append((180 - sekantenSteigungsWinkel[i+1] +␣

# ↪sekantenSteigungsWinkel[i])/2)

### ↪append(abs(sekantenSteigungsWinkel[len(sekantenSteigungsWinkel)-1]))

### [37]: winkelZwischenKloetzenHalbeWerte =␣ ↪winkelZwischenKloetzenHalbe(sekantenSteigungswinkelWerteListe)

### print("Winkel zwischen den Klötzen halbe (Schneidewinkel):")

### Winkel zwischen den Klötzen halbe (Schneidewinkel):

[78.898795820709, 89.22876825449512, 88.98487670797226, 88.60765928155607, 87.98411360890556, 86.86372107420078, 84.65543827770662, 80.18697753406784, 74.03904731943724, 74.03904731943724, 80.18697753406784, 84.65543827770662, 86.86372107420078, 87.98411360890556, 88.60765928155607, 88.98487670797226, 89.22876825449512, 78.898795820709]

## 2.3 Bestimmung der Klotzmaße

Zu Beginn wird die Länge der Sekanten, welche die Klötze beschreiben, bestimmt. Dies erfolgt, indem die Funktion mittels einer for-Schleife durch die Liste der x-Werte läuft und immer den aktuellen und den folgenden x-Wert nimmt und zu diesen die y-Werte bestimmt. Mit Hilfe des

## Satz von Pythagoras wird die Länge der Sekanten bestimmt. (siehe PDF Kapitel 6.5.1)

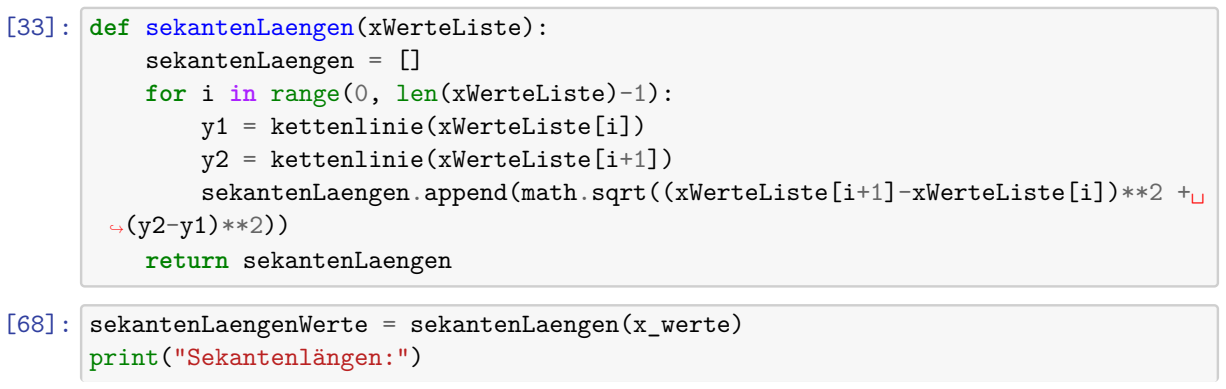
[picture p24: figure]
[33]: def sekantenLaengen(xWerteListe): sekantenLaengen = [] for i in range(0, len(xWerteListe)-1): y1 = kettenlinie(xWerteListe[i]) y2 = kettenlinie(xWerteListe[i+1]); return sekantenLaengen; print("Sekantenlängen:")

### sekantenLaengen.append(math.sqrt((xWerteListe[i+1]-xWerteListe[i])**2 +␣

↪(y2-y1)**2))

### [68]: sekantenLaengenWerte = sekantenLaengen(x_werte)

6

### print(sekantenLaengenWerte)

### Sekantenlängen:

[7.99981352543454, 7.999688518638961, 7.999441192504645, 7.998900408815565, 7.997555358723262, 7.993613801376608, 7.97979214105169, 7.931055451197266, 7.870234305111429, 7.931055451197266, 7.97979214105169, 7.993613801376608, 7.997555358723262, 7.998900408815565, 7.999441192504645, 7.999688518638961, 7.99981352543454]

Da die Sekanten durch die Mitte der Klötze läuft, kommen durch die Schräge beim schneiden auf der Außenseite des Bogens noch Längen dazu und innerhalb fallen genau diese weg (siehe PDF Kapitel 6.5.2). Die zusetzlichen Längen werden bestimmt, indem die Hälfte der Breite mit dem Tangens des jeweiligen Winkels im Klotz multipliziert wird, (siehe PDF Gleichung (33)).

### [48]: def zusetzlicheLaengenstuecke(winkelInHolzStueck):

### for i in range(0,len(winkelInHolzStueck)): langeSeite.append(2 / math.tan(math.radians(winkelInHolzStueck[i])))

### ↪zusetzlicheLaengenstuecke(winkelZwischenKloetzenHalbeWerte) #als Parameter␣ ↪wird winkelZwischenKloetzenHalbeWerte übergeben, da diese Winkel jenen in␣

# ↪den Klötzen sind

### Zusetzliche Längenelemente:

[0.39242805176953294, 0.026922692534157827, 0.03543819562185135, 0.04861142898944077, 0.07039676027437022, 0.10958625970258735, 0.18710338770379092, 0.3459281360982313, 0.5720159803737838, 0.5720159803737838, 0.3459281360982313, 0.18710338770379092, 0.10958625970258735, 0.07039676027437022, 0.04861142898944077, 0.03543819562185135, 0.026922692534157827, 0.39242805176953294]

## Da nun alle Größen bekannt sind, kann die außere Länge der Klotze bestimmt werden. Da der

erste und letzte Klotz von den anderen unterscheiden, liefert die folgende Methode nur die Mittleren Längen. Es wird die jeweilige Sekantenlänge mit den beiden zusetzlichen Länge addiert. Zu beachten ist, dass die beiden zusatzlängen Längen in einem Klotz verschieden voneinander sind.

### [50]: def laengeKloetzeAussenListe(sekantenLaengenListe, zusetzlicheLaengenListe): laengen = [] for i in range(0,len(sekantenLaengenListe)):#1 bis len-1 laengen.append(sekantenLaengenListe[i] + zusetzlicheLaengenListe[i] +␣

# ↪zusetzlicheLaengenListe[i+1])

### return laengen

7

### [62]: laengeKloetzeAussenWerteListe = laengeKloetzeAussenListe(sekantenLaengenWerte,␣

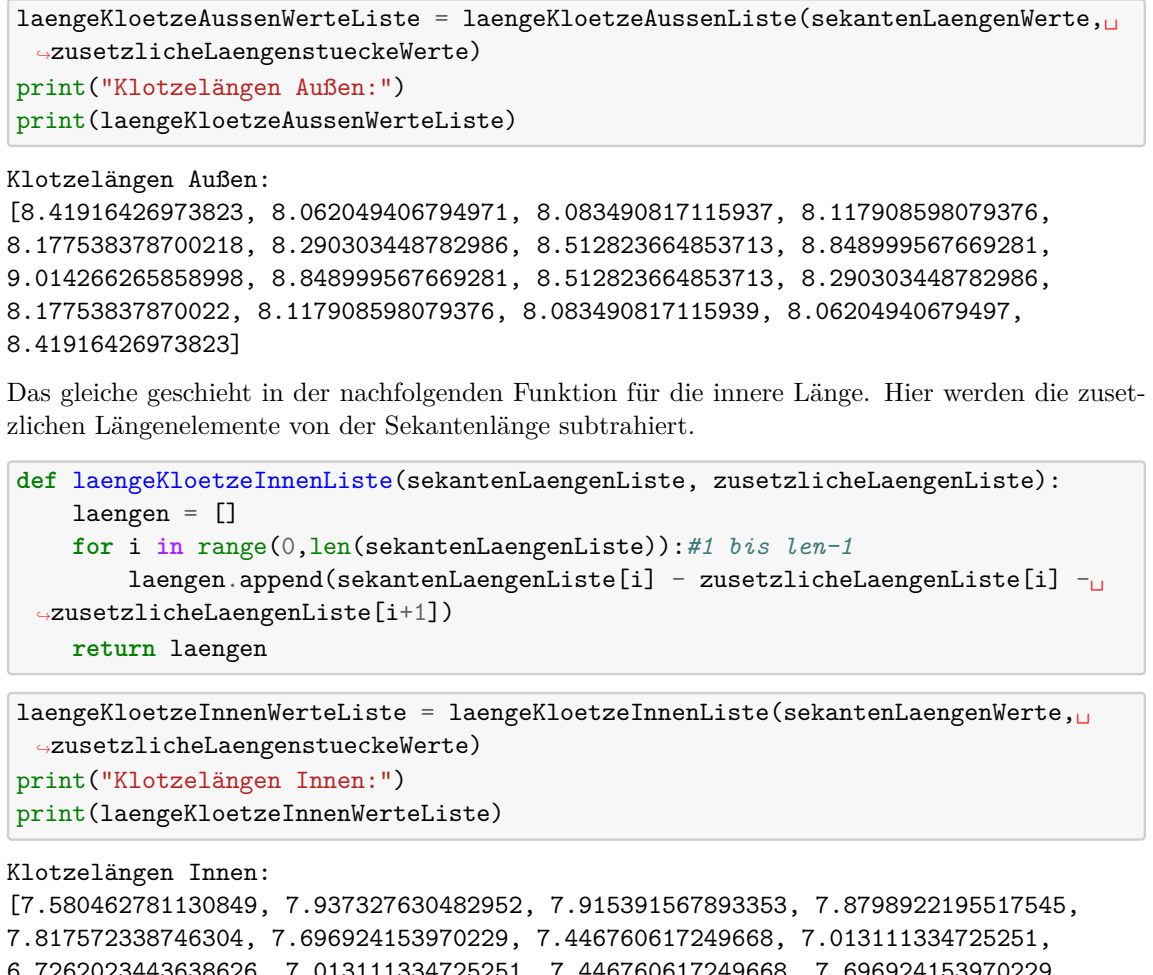
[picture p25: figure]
↪zusetzlicheLaengenstueckeWerte); print("Klotzelängen Außen:") print(laengeKloetzeAussenWerteListe); Klotzelängen Außen:; laengen = []; return laengen; print("Klotzelängen Innen:") print(laengeKloetzeInnenWerteListe); Klotzelängen Innen:

[8.41916426973823, 8.062049406794971, 8.083490817115937, 8.117908598079376, 8.177538378700218, 8.290303448782986, 8.512823664853713, 8.848999567669281, 9.014266265858998, 8.848999567669281, 8.512823664853713, 8.290303448782986, 8.17753837870022, 8.117908598079376, 8.083490817115939, 8.06204940679497,

Das gleiche geschieht in der nachfolgenden Funktion für die innere Länge. Hier werden die zusetzlichen Längenelemente von der Sekantenlänge subtrahiert.

### [52]: def laengeKloetzeInnenListe(sekantenLaengenListe, zusetzlicheLaengenListe):

### for i in range(0,len(sekantenLaengenListe)):#1 bis len-1 laengen.append(sekantenLaengenListe[i] - zusetzlicheLaengenListe[i] -␣

# ↪zusetzlicheLaengenListe[i+1])

### [54]: laengeKloetzeInnenWerteListe = laengeKloetzeInnenListe(sekantenLaengenWerte,␣

# ↪zusetzlicheLaengenstueckeWerte)

[7.580462781130849, 7.937327630482952, 7.915391567893353, 7.8798922195517545, 7.817572338746304, 7.696924153970229, 7.446760617249668, 7.013111334725251, 6.7262023443638626, 7.013111334725251, 7.446760617249668, 7.696924153970229, 7.817572338746304, 7.8798922195517545, 7.915391567893353, 7.937327630482952, 7.580462781130849]

## 2.4 Zeichnen der Kettenlinie

Die folgende Funktion zeichnet eine Funktion f, die als Parameter übergeben wird. Hier ist diese Funktion nützlich, da man sich so ein Bild von der Kettenlinie machen kann.

### [56]: def funktionZeichnen(f, xmin, xmax, label=None): x_values = np.linspace(xmin, xmax, 300) #eine Liste an x-Werten wird␣ ↪erzeugt. 300 x-Werte im Bereich zwischen xmin und xmax

### y_values = f(x_values) #die zugehörigen y-Werte werden bestimmt

### plt.axhline(0, color='black',linewidth=1) plt.axvline(0, color='black',linewidth=1)

8

### plt.plot(x_values, y_values, label=label) #die Punkte, die die x- und␣ ↪y-Werte bilden werden eingezeichnet, da es relativ viele sind, sieht es nach␣

### plt.title(f'Graph der Funktion {label}')

### [59]: funktionZeichnen(kettenlinie,-35,35, "Kettenlinie") #Funktionsaufruf mit der␣ ↪Gleichung der zuvor bestimmten Kettenlinie

## 2.5 Speichern der Klötze und graphische Kontrolle

Die nachfolgende Funktion, speichert die Klötze als stl-Datei ab und zeichnet die Klötze zur Kontrolle. Da diese Funktion realativ komplex ist, sind einzelne Befehle erklärt. Die Erklärungen sind

9

direkt hinter den Zeilen.

### [81]: def kloetzeAbspeichern(sekantenLaengen, laengeKloetzeAussen, zusetzlicheLaenge,␣ ↪x_werte, y_werte, sekantenSteigungswinkelListe):

### for n in range (0, len(laengeKloetzeAussen)): #Schleife läuft von Null bis␣

# ↪zur Anzahl der Klötze

### theta = np.radians(sekantenSteigungswinkelListe[n+1]) + np.radians(180)␣ ↪#theta ist der Winkel, um den der Klotz gedreht wird, bei n+1 weil trick mit␣ ↪erster und letzter klotz +180 da rechtsrum gedreht wird

### c, s = np.cos(theta), np.sin(theta) #in c wird der cosinus von theta␣

# ↪geschrieben, in s der sin

### R = np.array(((c, -s), (s, c))) #Drehmatrix R wird initialisiert (siehe␣

# ↪PDF Gleichung (7))

### die Koordinaten der Punkte werden bestimmt (siehe PDF Abbildung 26).␣ ↪Hier liegt der Klotz noch an dem Nullpunkt

### a = np.array([-zusetzlicheLaenge[n+1], 2]) b = np.array([ zusetzlicheLaenge[n+1],-2]) c = np.array([-zusetzlicheLaenge[n+1]+laengeKloetzeAussen[n], 2])

d = np.

### ↪array([-zusetzlicheLaenge[n+1]+laengeKloetzeAussen[n]-2*zusetzlicheLaenge[n],-2])

### v = np.array([x_werte[n+1], y_werte[n+1]]) #v ist der Ortsvektor des␣ ↪Punktes, der beim bestimmen der Koordinaten auf den Nullpunkt gelegt wurde

### die die Punkte a,b,c,d werden mit der Drehmatrix R multipliziert und␣ ↪mit dem Vektor v addiert und liegen jetzt auf der richtigen Stelle auf dem␣

# ↪Funktionsgraphen

### a1 = np.dot(R,a)+v b1 = np.dot(R,b)+v c1 = np.dot(R,c)+v d1 = np.dot(R,d)+v

### plt.rcParams["figure.figsize"] = [7.00, 3.50] #legt die Größe der␣ ↪Matplotlib-Figuren fest (Größen in Zoll)

### plt.rcParams["figure.autolayout"] = True #aktivieren das automatische␣

# ↪Layout

### polygon2 = Polygon([a1,c1,d1,b1,]) #eine Figur des Klotzes wird␣ ↪erstellt. Hierbei sind die Seiten a1c1 c1d1 d1b1 und b1a1

### x, y = polygon2.exterior.xy #der Variable x werden die x-Werte der␣ ↪Koordinaten zugeordnet, der Variable y die y-Werte

### plt.plot(x, y, c="black") #Die Punkte werden gezeichnet und gezeichnet␣

# ↪(mit den Seiten des polygon2)

10

### definition der Eckpunkte eines Klotzes a[0]/b[0]/... sind die␣ ↪x-Koordinaten der jeweiligen Punkte, a[1]/b[1]/... die y-Koordinaten

### 0 und vier sind die z-Koordinaten. Also ist ein Klotz hier 4LE hoch vertices = np.array([\

[a[0], a[1] , 0], #[-1, -1, -1], #0
[b[0], b[1] , 0], #[+1, -1, -1], #1
[d[0], d[1] , 0], #[+1, +1, -1], #2 [c[0], c[1] , 0], #[-1, +1, -1], #3 [a[0], a[1] , 4], #[-1, -1, +1], #4 [b[0], b[1] , 4], #[+1, -1, +1], #5
[d[0], d[1] , 4], #[+1, +1, +1], #6
[c[0], c[1] , 4]]) #[-1, +1, +1]]) #7

### die Flächen des Klotzes werden durch Dreiecke definiert faces = np.array([\

[0,3,1],
[1,3,2],
[0,4,7],
[0,7,3],
[4,5,6],
[4,6,7],
[5,1,2],
[5,2,6],
[2,3,6],
[3,7,6],
[0,1,5],
[0,5,4]])

### cube = mesh.Mesh(np.zeros(faces.shape[0], dtype=mesh.Mesh.dtype)) #ein␣ ↪Würfel mit den Flächen aus dem Array faces wird erzeugt

### for i, f in enumerate(faces): #schleife läuft über alle einträge im␣

# ↪faces array

### for j in range(3): #schleife läuft über die drei Eckpunkte eines␣

# ↪Dreiecks im faces Array

### cube.vectors[i][j] = vertices[f[j],:] #jetzt werden die␣ ↪Eckepunkte des cubes mit den Koordinaten aus dem vertices array gefüllt,␣ ↪also beschreibt dieser cube jetzt den aktuellen Klotz

### der cube wird als stl datei gespeichert (dateityp der für den druck␣ ↪verwendet wird). Hier ist der Befehl auskommentiert, da sonst beim Ausführen␣ ↪der Funktion direkt ohen Nachfrage die stl Dateien der Klötze abgespeichert␣

# ↪werden

### #cube.save('cube'+str(n)+'.stl')

### #die Funktion der Kettenlinie wird gezeichnet (gleiches Verfahren wie in␣

# ↪der Funktion zeichnen)

### x_values = np.linspace(-35, 35, 300)

11

### y_values = kettenlinie(x_values)

### plt.axhline(0, color='black',linewidth=1) plt.axvline(0, color='black',linewidth=1)

### plt.plot(x_values, y_values) plt.show()

### [82]: kloetzeAbspeichern(sekantenLaengenWerte, laengeKloetzeAussenWerteListe,␣ ↪zusetzlicheLaengenstueckeWerte, x_werte, y_werte,␣

Die Graphik ist verzerrt, führt man das Programm lokal aus, kann man die Fenstergröße anpassen,

### Diese Programmdokumentation kann unter https://andreas-di.github.io/jupyter/lab/

12








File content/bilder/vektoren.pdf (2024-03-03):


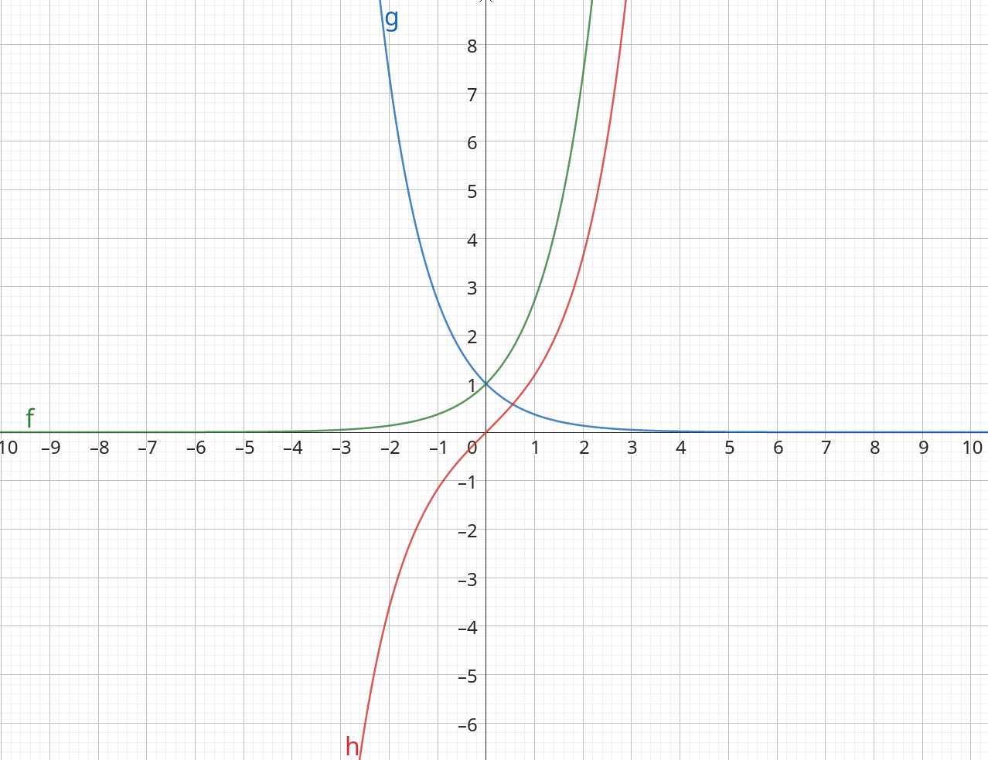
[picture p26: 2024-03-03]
content/bilder/sinh.png

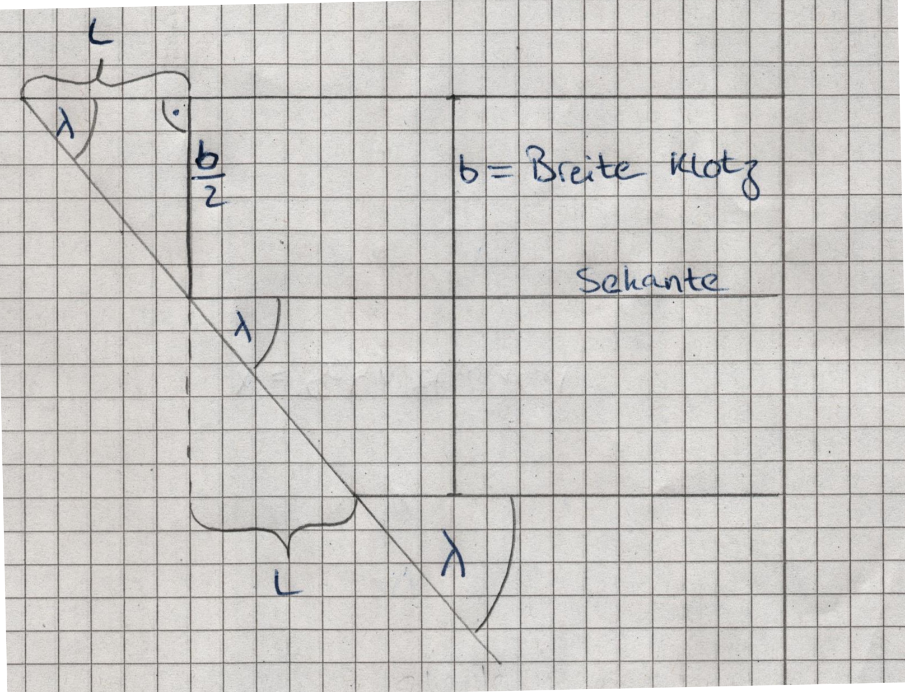
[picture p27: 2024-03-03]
content/bilder/laenge_aussen.png

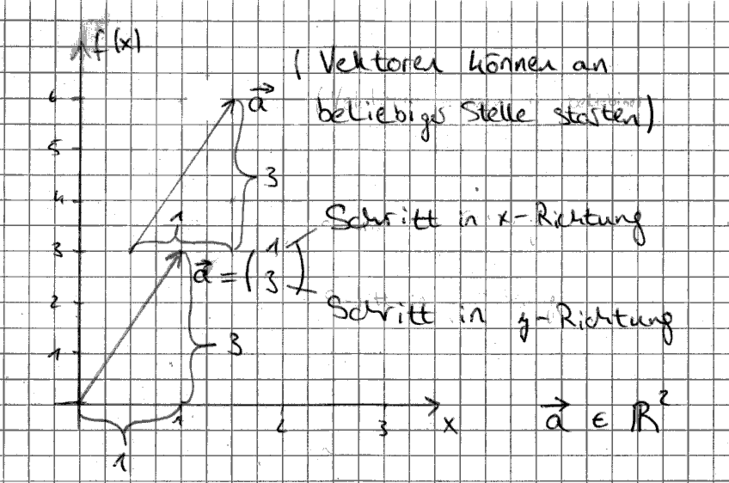
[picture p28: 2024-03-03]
content/bilder/vektoren_r2.png

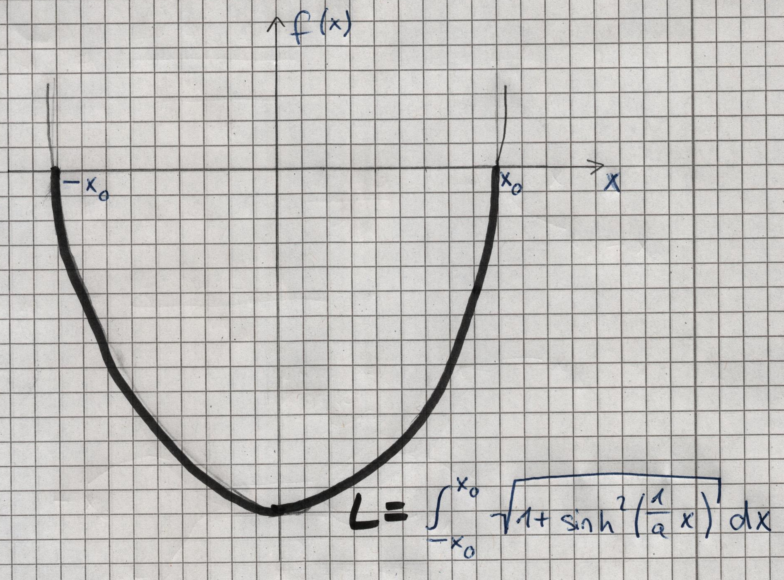
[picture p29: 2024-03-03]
content/bilder/bogenlaenge_insgesamt.png

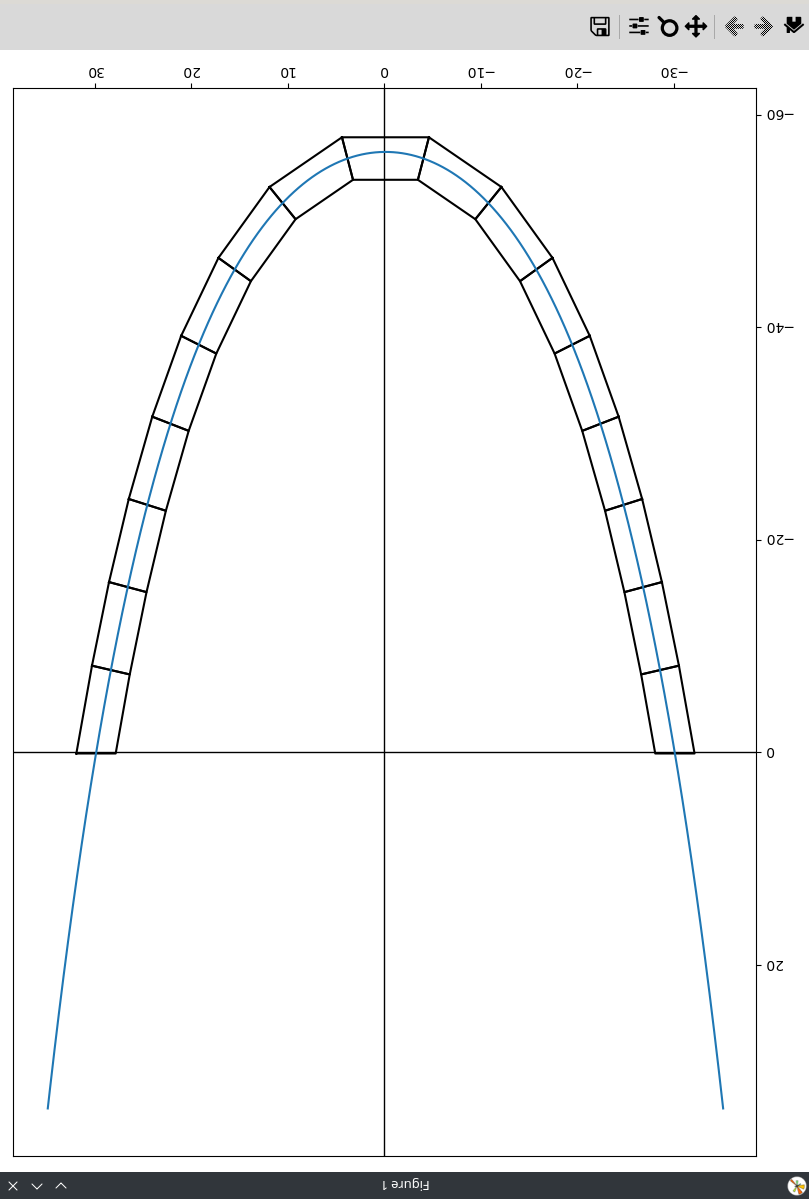
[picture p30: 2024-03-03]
content/bilder/plot_mit_stuecken_umgedreht.png

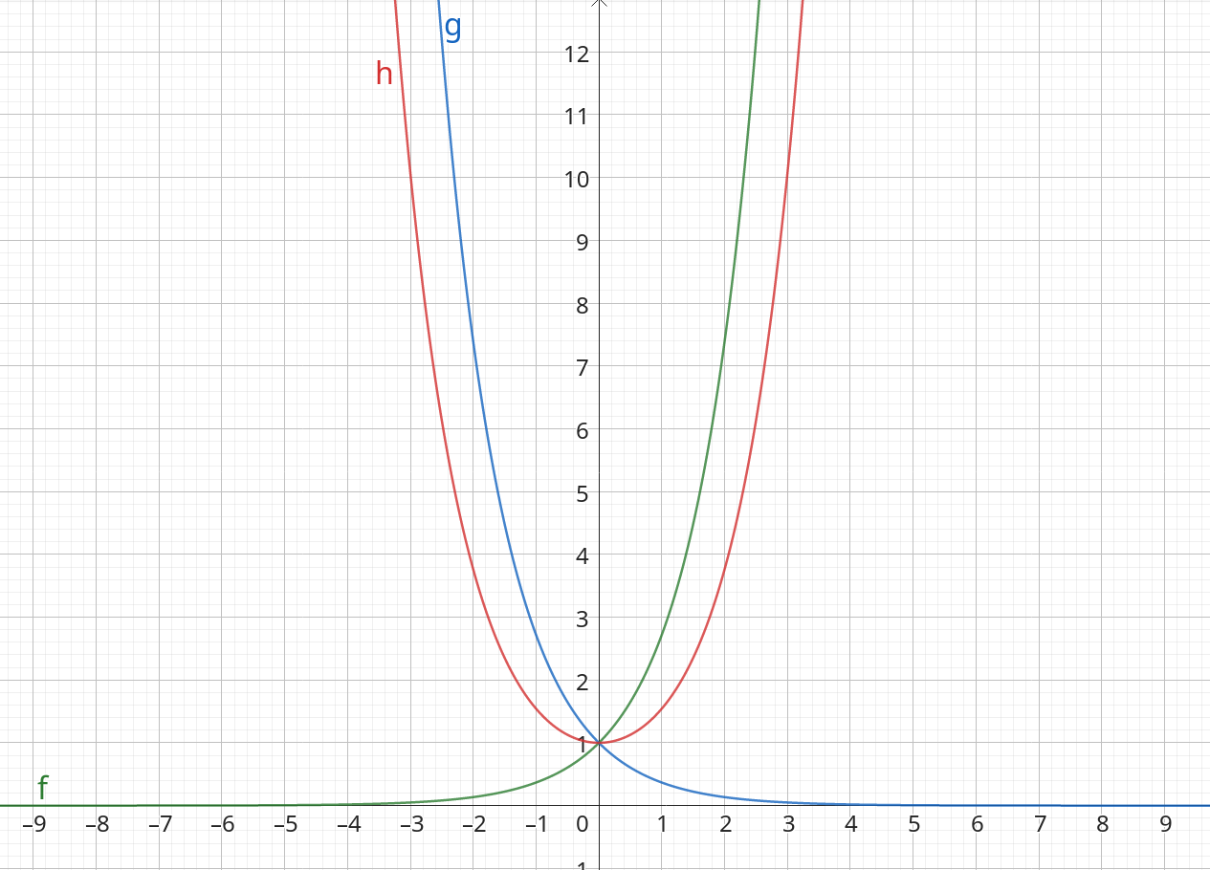
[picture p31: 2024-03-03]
content/bilder/cosh.png

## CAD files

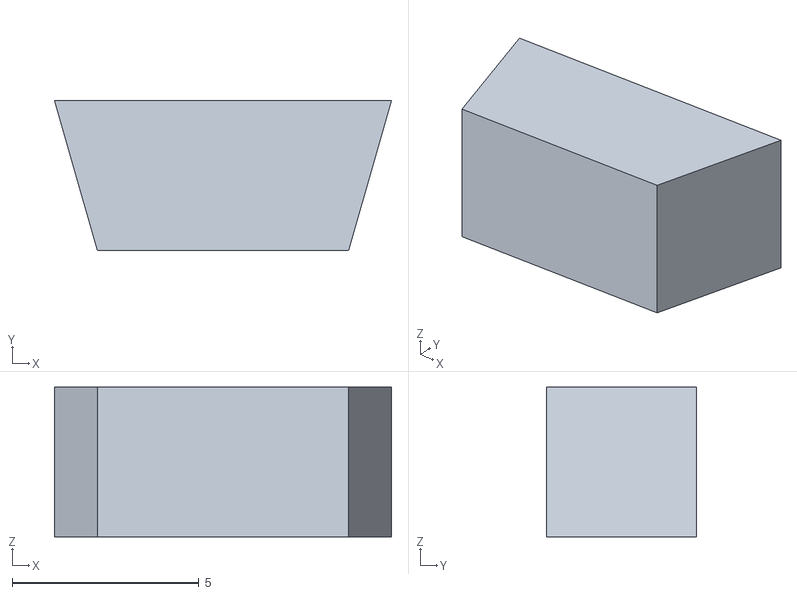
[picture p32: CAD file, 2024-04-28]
stl_Dateien/cube8.stl
9.01 x 4.00 x 4.00

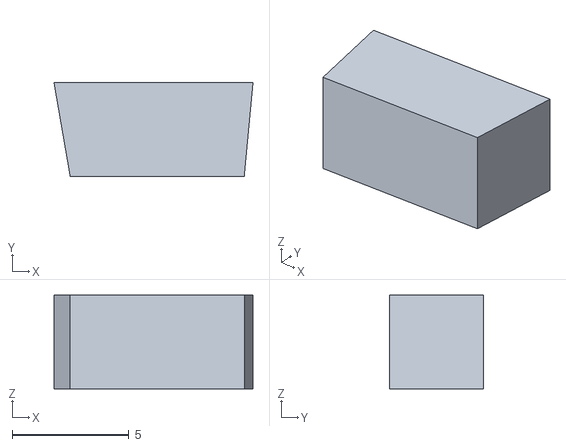
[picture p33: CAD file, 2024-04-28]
stl_Dateien/cube6.stl
8.51 x 4.00 x 4.00

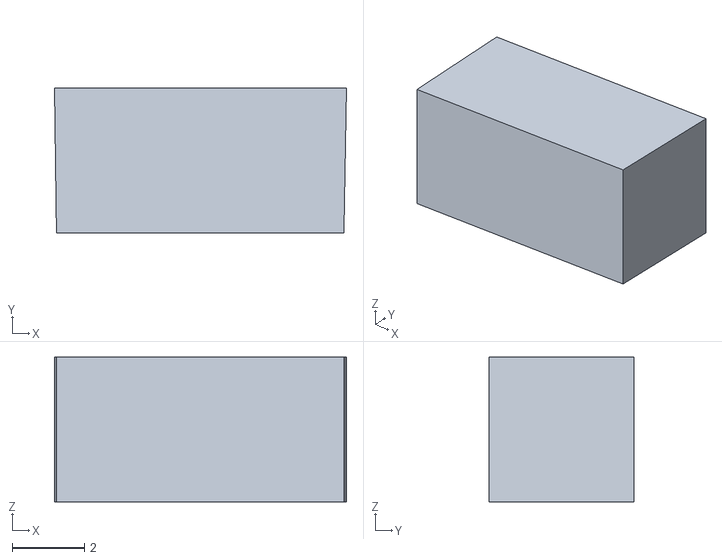
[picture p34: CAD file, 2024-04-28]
stl_Dateien/cube15.stl
8.06 x 4.00 x 4.00

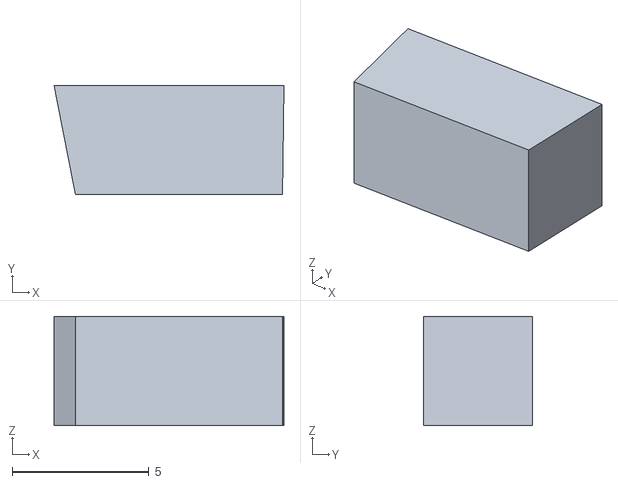
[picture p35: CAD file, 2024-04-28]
stl_Dateien/cube16.stl
8.42 x 4.00 x 4.00

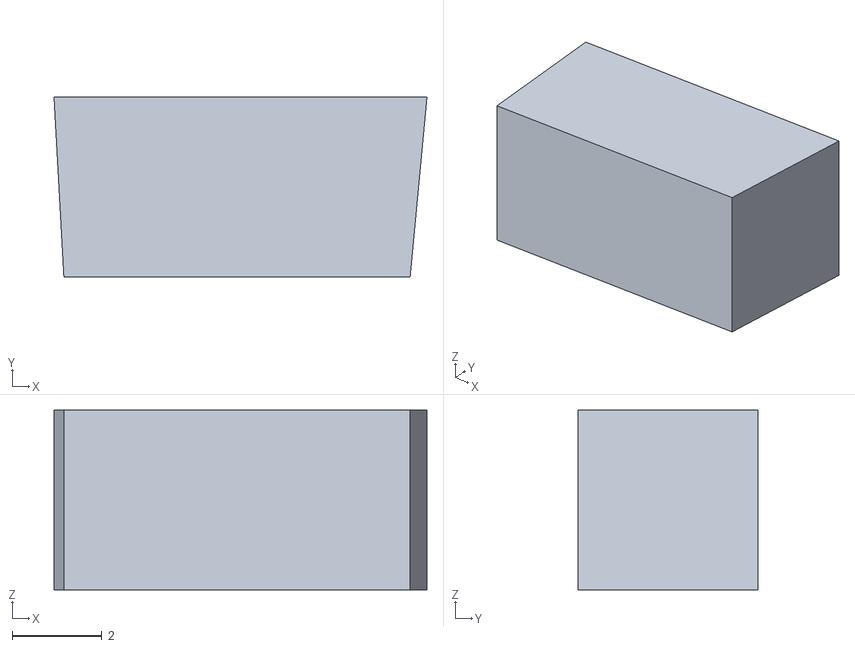
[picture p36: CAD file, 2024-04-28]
stl_Dateien/cube11.stl
8.29 x 4.00 x 4.00

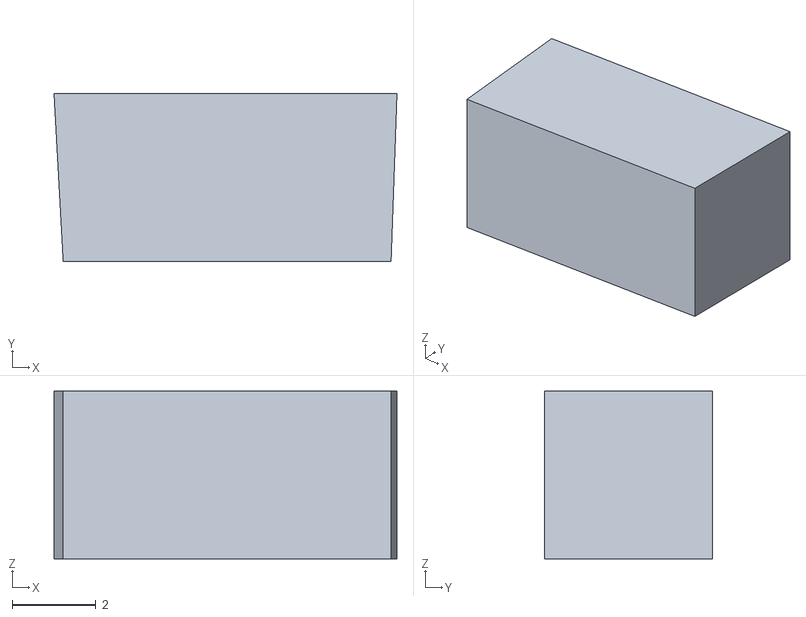
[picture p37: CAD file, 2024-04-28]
stl_Dateien/cube4.stl
8.18 x 4.00 x 4.00

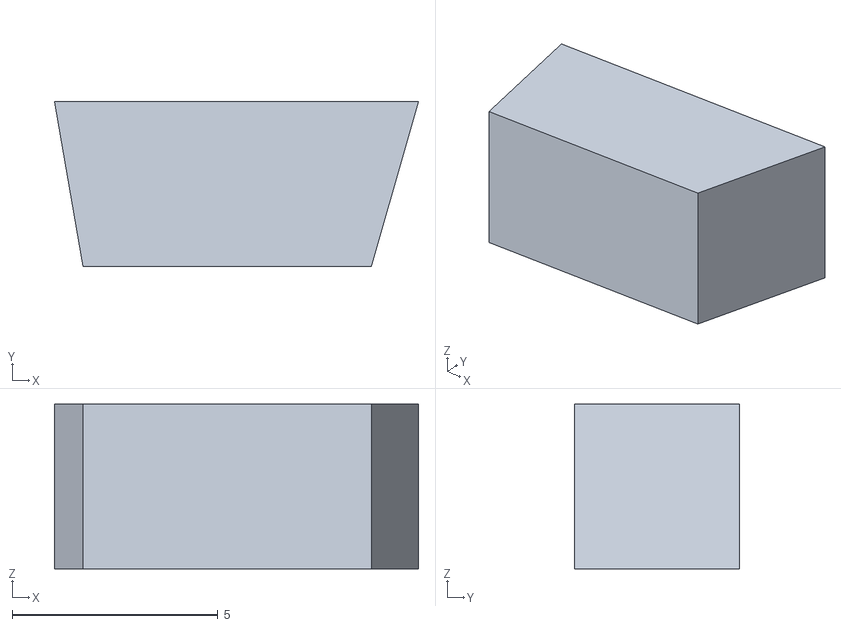
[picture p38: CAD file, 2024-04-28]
stl_Dateien/cube9.stl
8.85 x 4.00 x 4.00

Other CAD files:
stl_Dateien/cube3.stl
stl_Dateien/cube14.stl
stl_Dateien/cube10.stl
stl_Dateien/cube2.stl
stl_Dateien/cube1.stl
stl_Dateien/cube0.stl
stl_Dateien/cube13.stl
stl_Dateien/cube12.stl
stl_Dateien/cube5.stl
stl_Dateien/cube7.stl

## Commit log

2024-03-03 bilder und kettenlinie
2024-04-27 loeschen beispieldateien
    [iris.csv]
2024-04-27 read me und dateiname
2024-04-28 pdf py und stl
    [cube0.stl, cube1.stl, cube10.stl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]
